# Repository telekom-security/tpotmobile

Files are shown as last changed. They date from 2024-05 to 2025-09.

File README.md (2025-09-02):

The idea for T-Pot Mobile started a couple of years back when T-Pot started to support the ARM64 architecture. Raspberry Pi hardware was hard to come by at reasonable prices so the journey took a little longer than anticipated. Started as a one-day-a-month project at work, it fastly turned into a weekend / evening project (winter was coming) and the first version was done in [December 2023](https://www.linkedin.com/posts/mochse_telekomsecurity-cyberdefense-raspberrypi-activity-7138560366661300224-Ccra).<br><br>
While already being an eye catcher the display was not bright enough, the resistive touchpanel and the resolution really did limit the possibilities. In consequence a new display had to be found that helped overcome the drawbacks. The Waveshare 4.3" capacitive display was a great choice with a higher resolution.<br><br>
**Bigger is better** - and in this case (pun intended) it is really true. T-Pot Mobile now supports an 8" display to make it an even bigger eye catcher!<br><br> To support the 8" display alongside the 4.3" a new case had to to be created while adjusting the code to make use of the added screen estate. <br><br>
We are very happy to share this project continiously as open source, with a huge thanks to [Telekom Security](https://geschaeftskunden.telekom.de/digitale-loesungen/cyber-security) to make this possible.<br><br>
**Create yours today, all files for 3d printing included!**

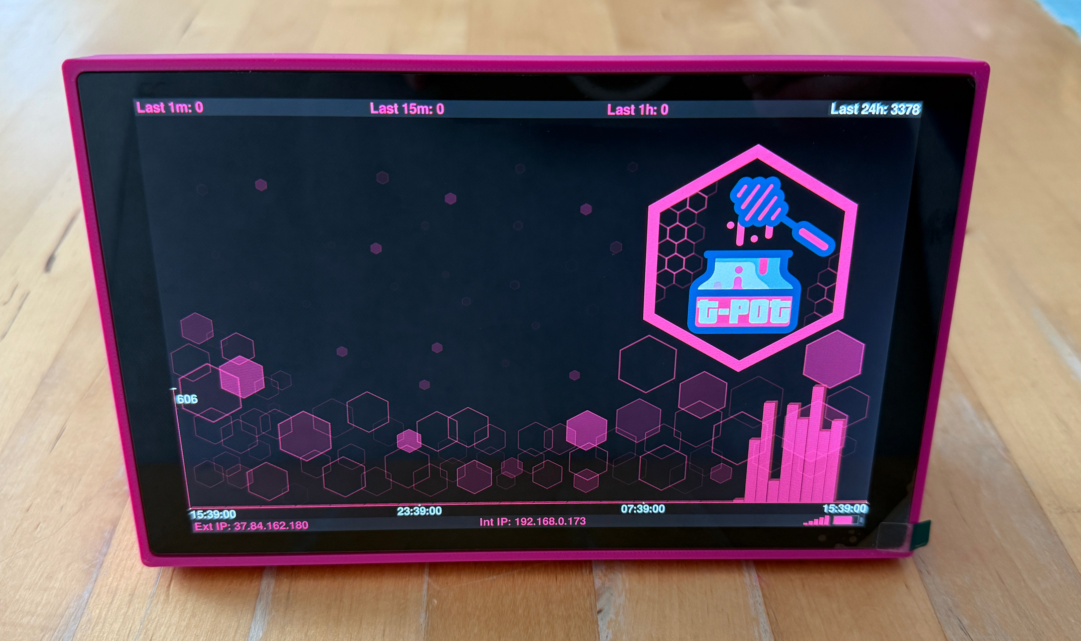
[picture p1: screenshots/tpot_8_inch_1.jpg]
T-Pot 8 inch 1


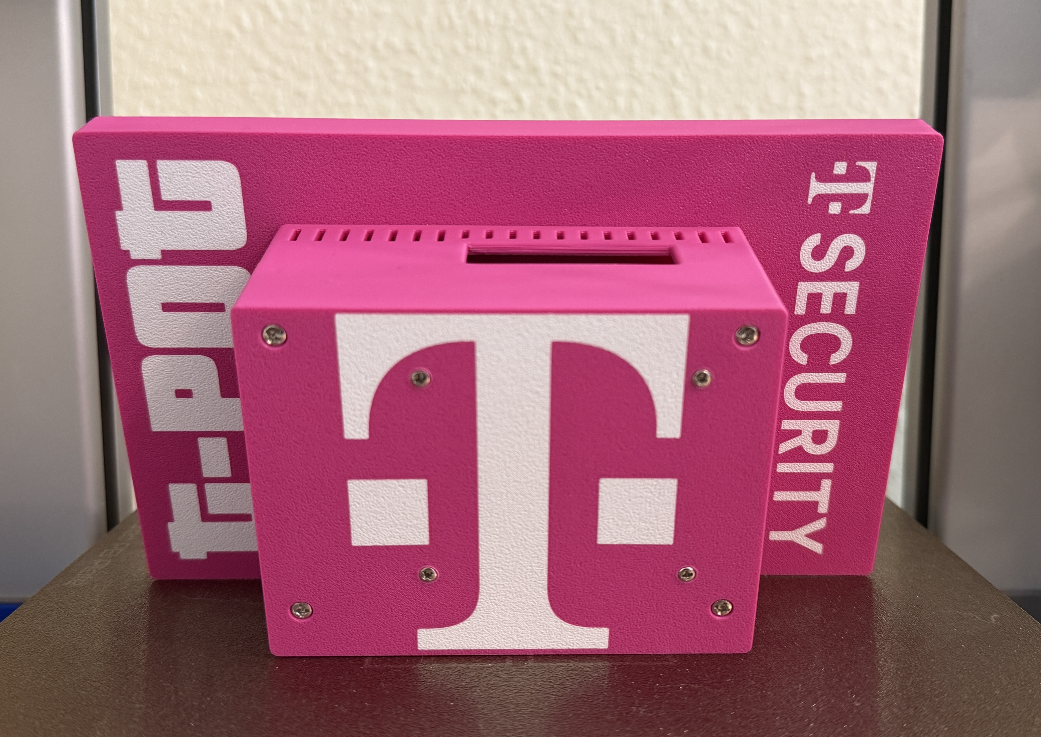
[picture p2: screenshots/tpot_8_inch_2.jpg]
T-Pot 8 inch 2


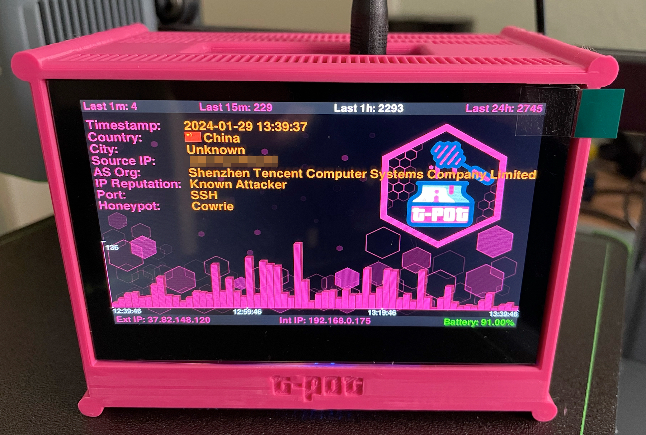
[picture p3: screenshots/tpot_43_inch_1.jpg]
T-Pot 4.3 inch 1


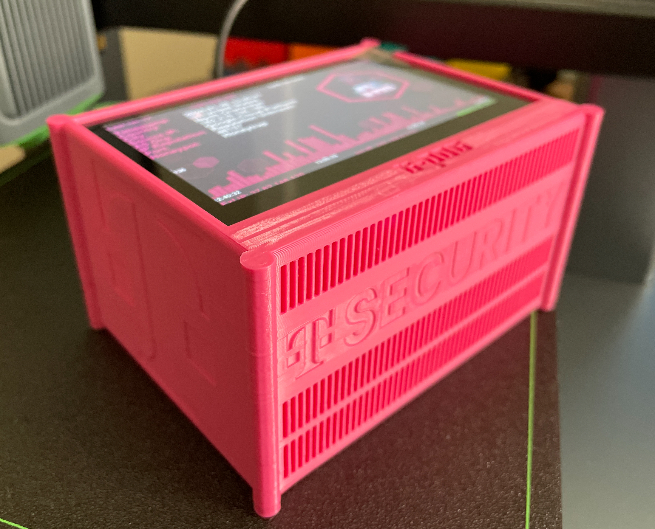
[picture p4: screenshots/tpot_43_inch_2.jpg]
T-Pot 4.3 inch 2


# T-Pot Mobile

<!-- vscode-markdown-toc -->
* 1. [Hardware requirements](#Hardwarerequirements)
	* 1.1. [8 inch](#inch)
	* 1.2. [4.3 inch](#inch-1)
* 2. [Requirements](#Requirements)
* 3. [Installation](#Installation)
	* 3.1. [One liner installation](#Onelinerinstallation)
	* 3.2. [Manual installation](#Manualinstallation)
* 4. [LTE Stick settings](#LTESticksettings)
* 5. [Usage](#Usage)
	* 5.1. [Turn on](#Turnon)
	* 5.2. [Turn off](#Turnoff)
* 6. [T-Pot Mobile UI](#T-PotMobileUI)
	* 6.1. [Waiting for Elasticsearch](#WaitingforElasticsearch)
	* 6.2. [Stats Mode](#StatsMode)
	* 6.3. [Map Mode](#MapMode)
	* 6.4. [Open Dialog Box](#OpenDialogBox)
		* 6.4.1. [Cancel](#Cancel)
		* 6.4.2. [Map / Stats](#MapStats)
		* 6.4.3. [Reboot](#Reboot)
		* 6.4.4. [Power Off](#PowerOff)
* 7. [Maintenance and Troubleshooting](#MaintenanceandTroubleshooting)
	* 7.1. [Connect a keyboard](#Connectakeyboard)
	* 7.2. [Exit the GUI](#ExittheGUI)
	* 7.3. [Starting / Stopping T-Pot services](#StartingStoppingT-Potservices)
	* 7.4. [Cronjob](#Cronjob)
	* 7.5. [Updates](#Updates)
	* 7.6. [Network Settings](#NetworkSettings)
* 8. [3d Print Settings](#dPrintSettings)
* 9. [Assembling the parts - 8 inch](#Assemblingtheparts-8inch)
* 10. [Assembling the parts - 4.3 inch](#Assemblingtheparts-4.3inch)
* 11. [Credits](#Credits)
* 12. [Licenses](#Licenses)

<!-- vscode-markdown-toc-config
	numbering=true
	autoSave=true
	/vscode-markdown-toc-config -->
<!-- /vscode-markdown-toc -->

##  1. Hardware requirements

T-Pot Mobile is developed specifically to make T-Pot a tangible, fully wireless honeypot using hardware components for:
<details>

<summary>

###  1.1. 8 inch

</summary>

- [Raspberry Pi 4 model B](https://www.raspberrypi.com/products/raspberry-pi-4-model-b/) with 8GB of RAM, 64GB microSD card
- [Waveshare 8" touch display](https://www.waveshare.com/8inch-dsi-lcd-c.htm)
- [Waveshare UPS HAT](https://www.waveshare.com/wiki/UPS_HAT) with 2 * 18650 batteries
- [ZTE MF79U Wingle CAT4-4G](https://www.amazon.de/gp/product/B08WPXRTRL) with the USB plug removed
- Nuts and standoff assortment for [M2.5](https://www.amazon.de/gp/product/B08M3BVC9Q) and [M3](https://www.amazon.de/gp/product/B08M3BVC9Q?th=1)

</details>

<details>

<summary>

###  1.2. 4.3 inch

</summary>

- [Raspberry Pi 4 model B](https://www.raspberrypi.com/products/raspberry-pi-4-model-b/) with 8GB of RAM, 64GB microSD card
- [Waveshare 4.3" touch display](https://www.waveshare.com/wiki/4.3inch_DSI_LCD), make sure to order the version including the [case](https://www.amazon.de/dp/B08LH5MFVS)
- [Waveshare UPS HAT](https://www.waveshare.com/wiki/UPS_HAT) with 2 * 18650 batteries
- [ZTE MF79U Wingle CAT4-4G](https://www.amazon.de/gp/product/B08WPXRTRL) with the USB plug removed
- [Nuts and standoff assortment](https://www.amazon.de/gp/product/B08M3BVC9Q) 

</details>

Regarding the hardware limits of the Raspberry Pi4 platform (mainly RAM and storage) T-Pot Mobile will use a `docker-compose.yml` specifically adjusted for this use case.

##  2. Requirements

- Raspbian Lite, 64bit based on Raspbian / Debian Bookworm
- At least T-Pot 24.04.0 which will be installed by the T-Pot Mobile installer
- Prepare the microSD Card with a user i.e. `tsec` and the WiFi settings for your local network (adjustments of the Wifi settings are described [here](#network-settings))

##  3. Installation

###  3.1. One liner installation
`env bash -c "$(curl -sL https://github.com/telekom-security/tpotmobile/raw/main/install.sh)"`

###  3.2. Manual installation
Boot the machine, SSH into Raspbian on `tcp/22`, run the following commands and follow the installer:
```
sudo apt install git
git clone https://github.com/telekom-security/tpotmobile
cd tpotmobile
bash install.sh
```

The `install.sh` script will also install T-Pot. When the installer asks for a T-Pot type, please choose `(M)obile` in order to download the correct docker images.

Then `sudo reboot` the machine, please notice after the reboot SSH will only be available via `tcp/64295`.

It takes about 8 minutes until all services are started successfully after installation.

##  4. LTE Stick settings
- Login: Factory default, adjust after setup
- SSID: Factory default, adjust after setup
- PSK: Factory default, adjust after setup
- For Telekom in Germany: Setup the LTE stick to use [APN with NAT Type 2](https://telekomhilft.telekom.de/t5/Mobilfunk/NAT-Typ-amp-APN-Einstellungen/td-p/3295081): `internet.t-d1.de`.
- Use NAT forwarding only for ports 1-64000 to avoid exposing T-Pot management ports, such as SSH.
- For DHCP / MAC settings ensure that the same IP will always be assigned to the T-Pot Wifi Adapter or NAT will break once a new IP lease starts.

##  5. Usage
###  5.1. Turn on
- After turning the device on (UPS HAT power switch in on-position) the device will automatically boot and wait for the mobile network / WiFi to be fully enabled.
- It takes roughly 8-10 minutes until all services have been started, then the first events should trickle in.
###  5.2. Turn off
- After [Shutting Down](#power-off) the device can be turned off (UPS HAT power switch in off-position). Always shutdown the device first to avoid damaging the elasticsearch index and / or filesystem.

##  6. T-Pot Mobile UI
The UI has been developed using Pygame (Raspbian / Debian Bookworm is fully supported and required).<br>
###  6.1. Waiting for Elasticsearch
- Once the device has started the UI will wait for Elasticsearch to be available, afterwards the UI will switch into stats mode (default: Last 1h). The UI can be fully utilized once events have been written to the Elasticsearch index.
###  6.2. Stats Mode
- A single touch will switch between the available timeframes (Last 1m, 15m, 1h, 24h).
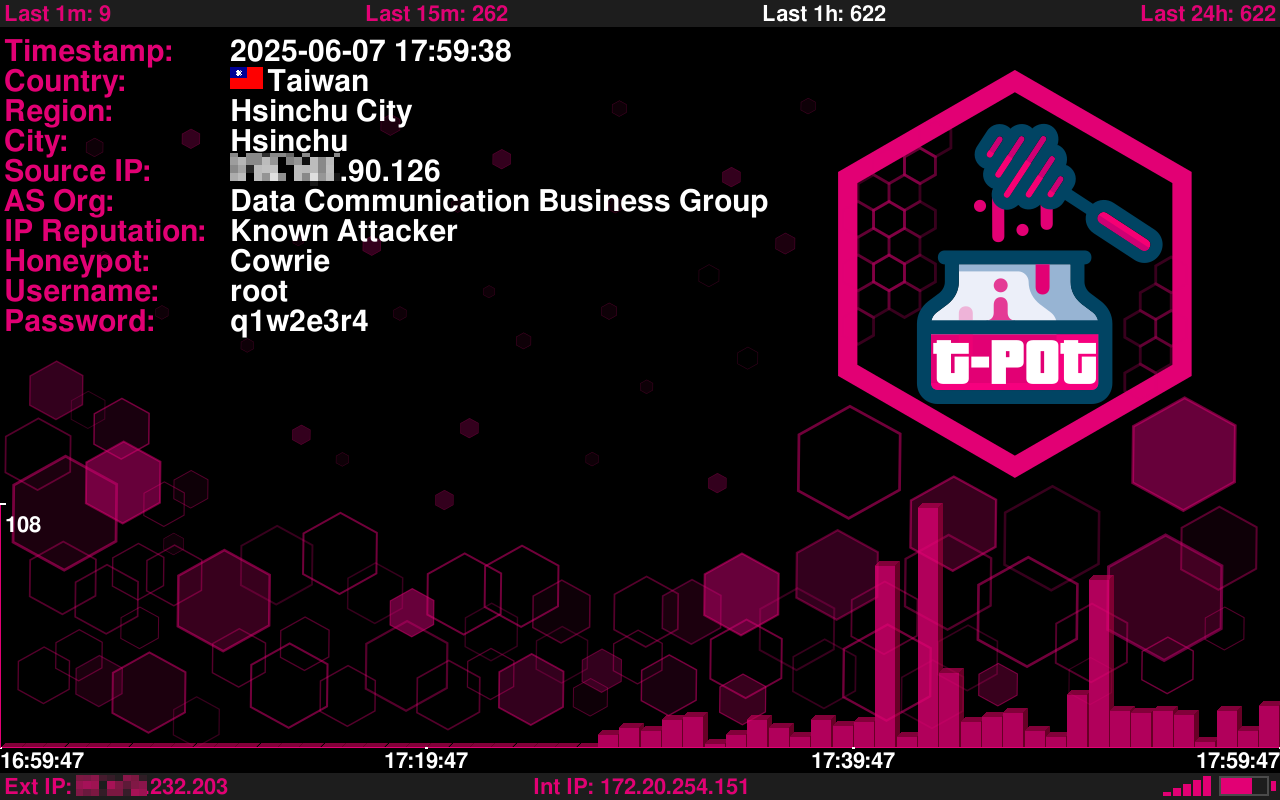
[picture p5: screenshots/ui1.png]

###  6.3. Map Mode
- In Map Mode the UI will display the events on a map utilizing some animations.
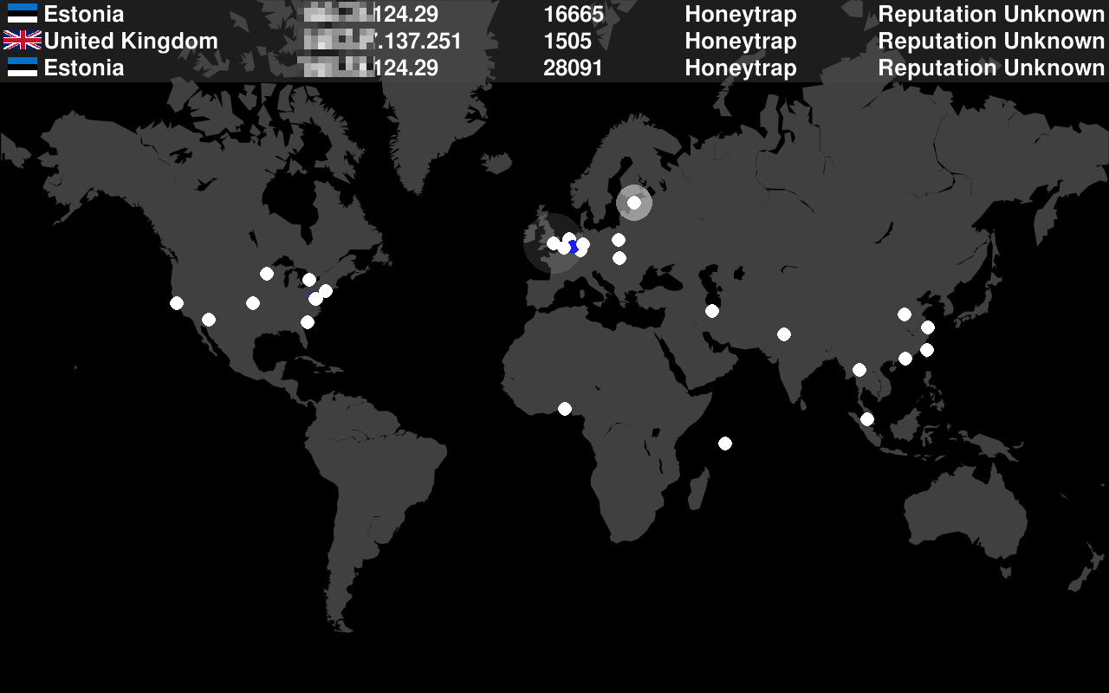
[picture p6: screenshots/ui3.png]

###  6.4. Open Dialog Box
- Swiping up from the bottom of the screen towards the top of the screen (at least half the height of the screen) will open the dialog box.
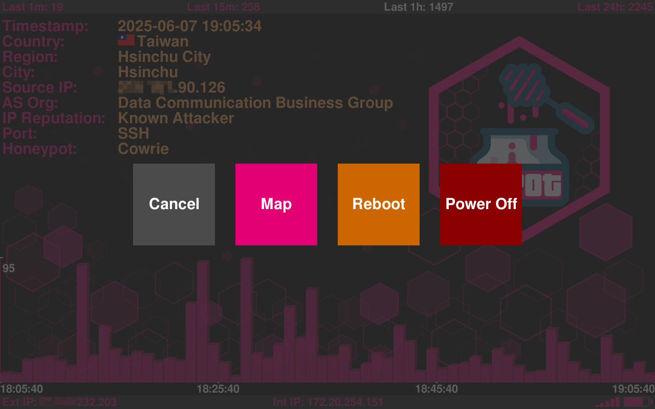
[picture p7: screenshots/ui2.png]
<br>
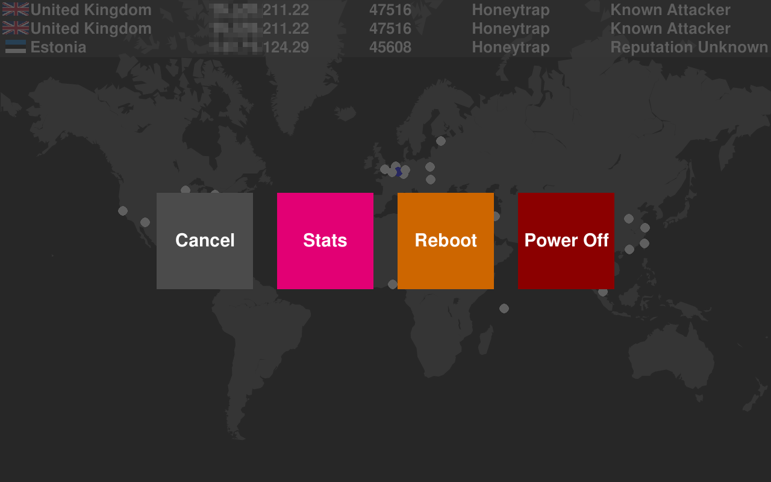
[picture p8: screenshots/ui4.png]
<br>
####  6.4.1. Cancel
- Will exit the dialog box. 
####  6.4.2. Map / Stats
- While in Stats mode the button will be called "Map" and when pressed will open the Map mode.
- While in Map mode the button will be called "Stats" and when pressed will open the Stats mode.
####  6.4.3. Reboot
- The Reboot button will reboot the system. 
####  6.4.4. Power Off
- The Power Off button will shut down the system. The system is designed for 24/7 operation, however it needs to be turned off using the Power Off function to avoid damaging the file system or elastic search indices.

##  7. Maintenance and Troubleshooting
###  7.1. Connect a keyboard
- For troubleshooting you can connect a keyboard.
###  7.2. Exit the GUI
- Press `q` to exit the GUI.
- Login to the system with your username, i.e. `tsec` and the password you chose.
- You now have access to the console as with any other Raspbian / Debian installation.
###  7.3. Starting / Stopping T-Pot services
- In `/etc/systemd/system` are the T-Pot systemd service files `tpot.service` and `tpotdisplay.service` located. While `tpot.service` does control the T-Pot services `tpotdisplay.service` controls the T-Pot Mobile GUI.
- Start T-Pot: `sudo systemctl start tpot.service`
- Start T-Pot Mobile GUI: `sudo systemctl start tpotdisplay.service`
- Stop T-Pot: `sudo systemctl stop tpot.service`
- Stop T-Pot Mobile GUI: `sudo systemctl stop tpotdisplay.service`
###  7.4. Cronjob
- T-Pot Mobile will restart the device by default every day. You can change the cronjob settings with `sudo crontab -e`.
###  7.5. Updates
- While OS updates will be installed automatically the docker image pull policy is set to `missing`. This means even if newer image versions are available `docker compose` will not pull them. If your mobile connection is perfectly fine with downloading large docker image files then you can adjust `TPOT_PULL_POLICY` in `tpotce/.env` to `always`. Otherwise install updates using a different network connection i.e. LAN / WiFi.
- Update tpotce: `cd tpotce && sudo systemctl stop tpot && git pull`
- Update tpotmobile: `cd tpotmobile && sudo systemctl stop tpotdisplay && git pull`
- Update docker images: `cd tpotce && docker compose -f docker-compose.yml pull`
###  7.6. Network Settings
- Raspbian uses Network Manager by default.
- You can find and adjust network connections in `/etc/NetworkManager/system-connections`.
- By default you will find `preconfigured.nmconnection` which contains the settings provided by Raspberry Pi Imager.

##  8. 3d Print Settings
For 3d printing we were using PLA+ filament with the following settings, depending on your usage other filament types need to be considered i.e. PETG, ABS or ASA (those remain untested regarding the case).
- #### Layers and perimeters
  - Layer height 0,2mm
  - 5 solid base and top layers with monotonic lines
  - 6 walls
- #### Infill
  - 25%
- #### Speed
  - Initial layer: 50mm/s
  - Outer wall: 60mm/s
- #### Supports enabled
    - Style: Grid
    - Top / bottom contact Z distance: 0.2 (reduce top to 0.1 may increase quality)
    - Base Pattern: Rectilinear grid
    - Pattern angle: 90°
    - Top / bottom interface layers: 2
    - Interface Pattern: Rectilinear

<details>

<summary>

##  9. Assembling the parts - 8 inch

</summary>

####
Overview of all the parts you will need to assemble T-Pot Mobile.
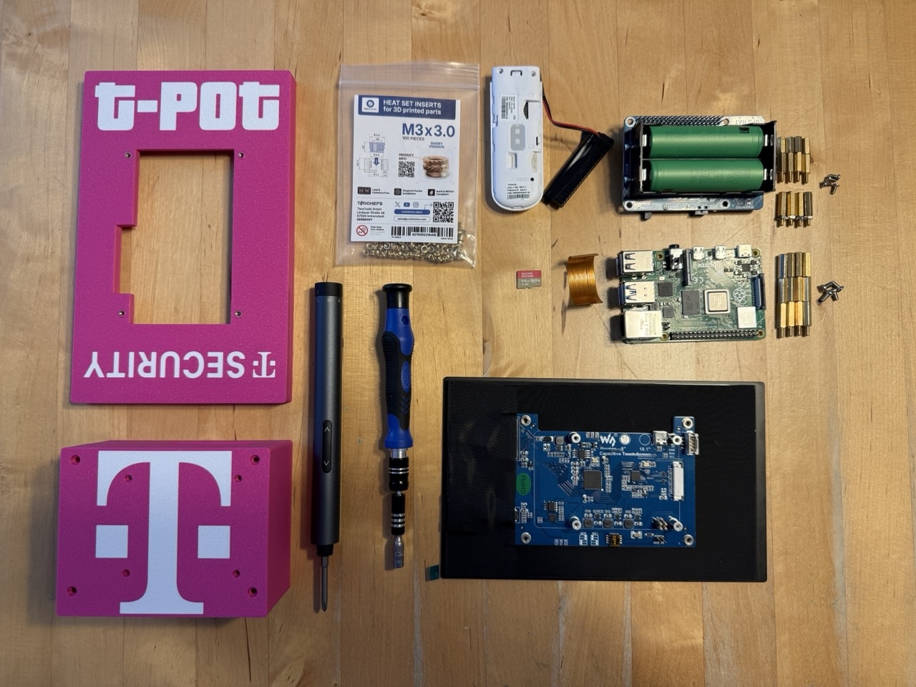
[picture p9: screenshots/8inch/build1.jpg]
Build 1


#### 
Insert the microSD card into the Pi4, **after** installing Raspbian. It will be harder to reach the microSD card later in the process.
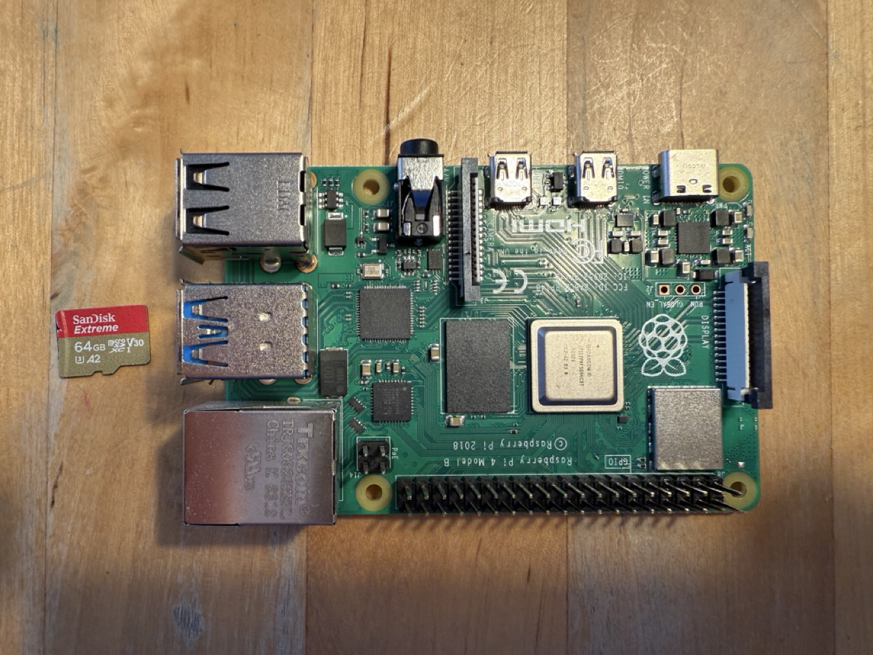
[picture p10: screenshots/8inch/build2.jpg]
Build 2

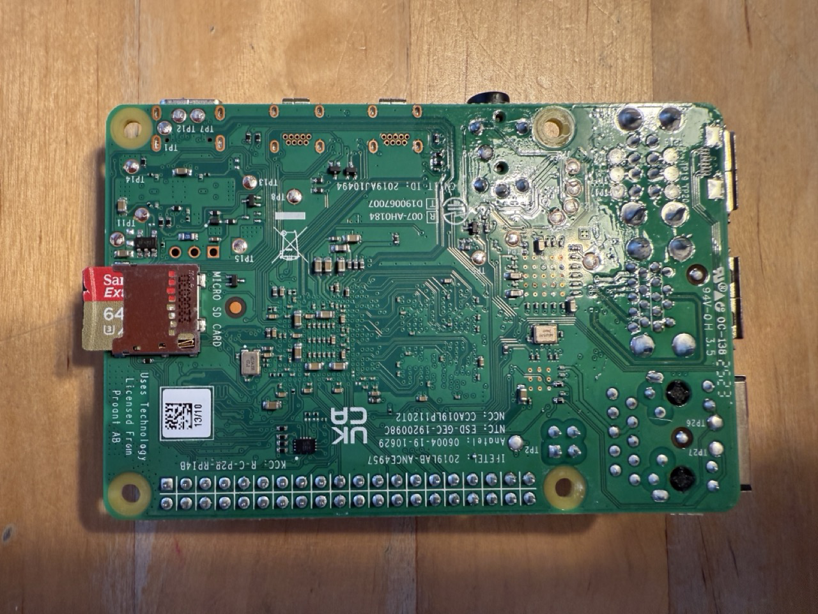
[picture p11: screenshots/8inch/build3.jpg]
Build 3


#### 
Place the screen in front of you, face down.
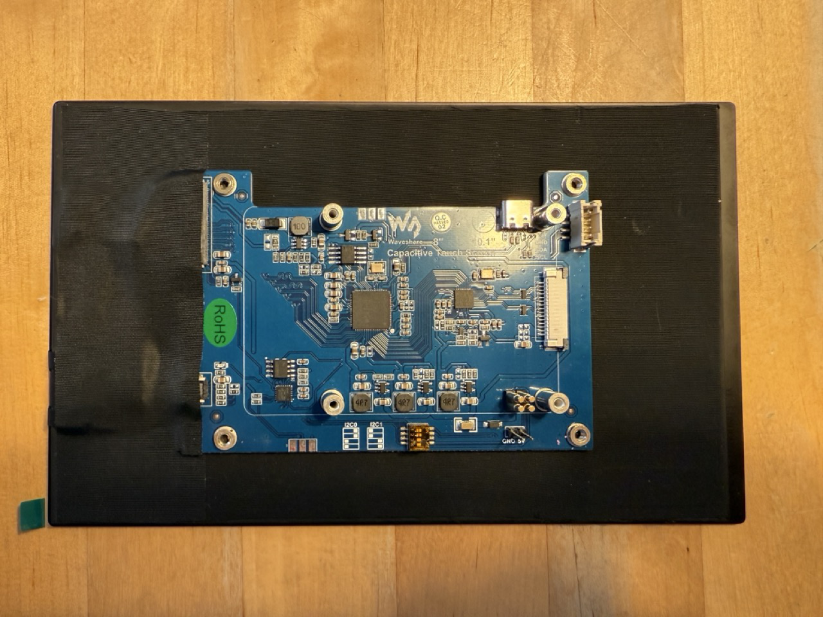
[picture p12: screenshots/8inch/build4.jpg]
Build 4


#### 
Align the Raspberry Pi on the standoffs and use the nuts (4 x M2.5) and standoffs (4 x M2.5x15 + 6) from the assortment to secure it. Also check the pogo pins align properly between the Pi and the display.
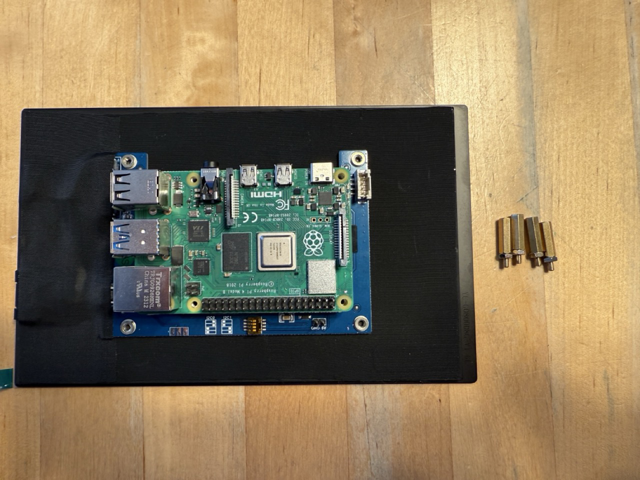
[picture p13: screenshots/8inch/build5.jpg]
Build 5

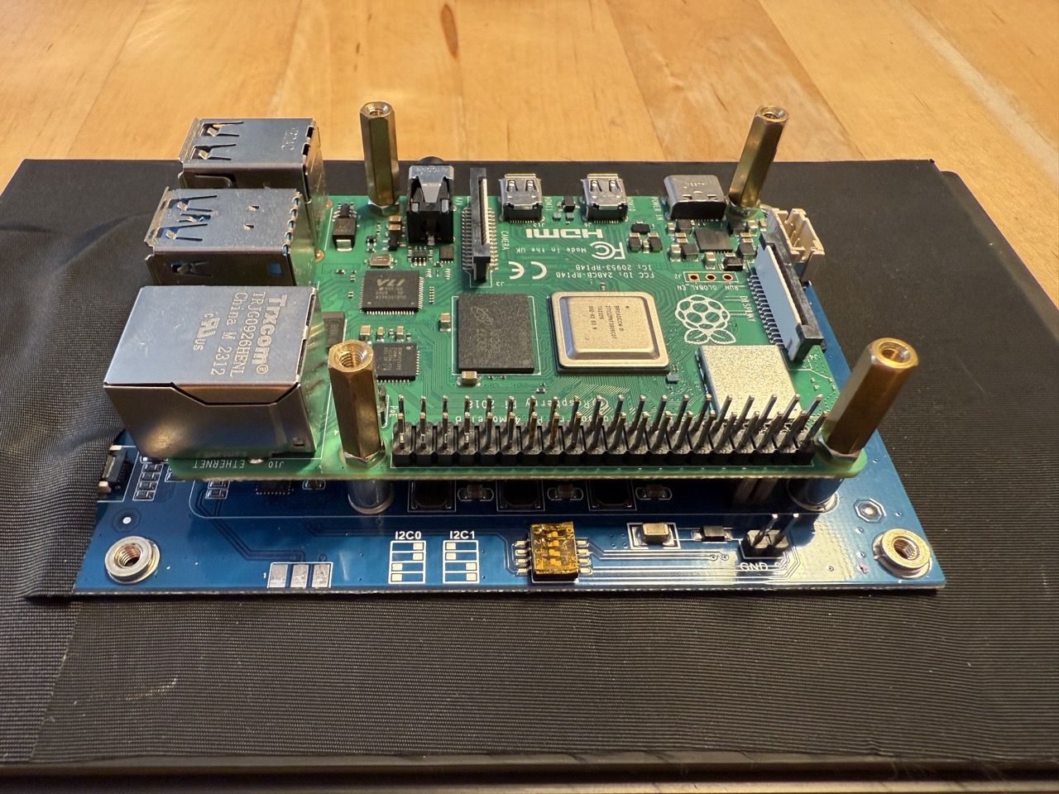
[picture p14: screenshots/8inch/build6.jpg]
Build 6


#### 
Insert the flex DSI cable and ensure the cable and socket connectors align and the pins face each other.
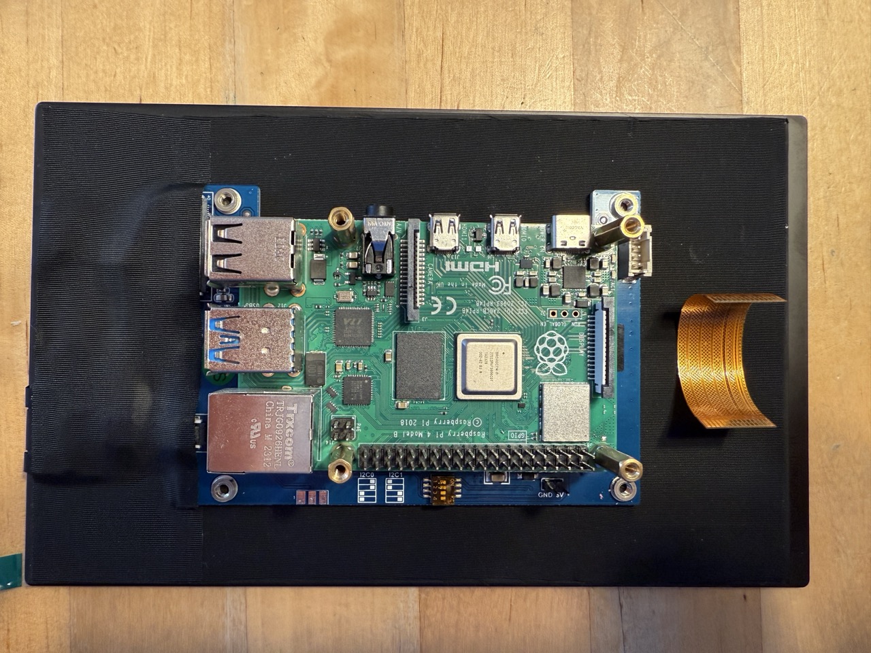
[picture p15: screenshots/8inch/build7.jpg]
Build 7

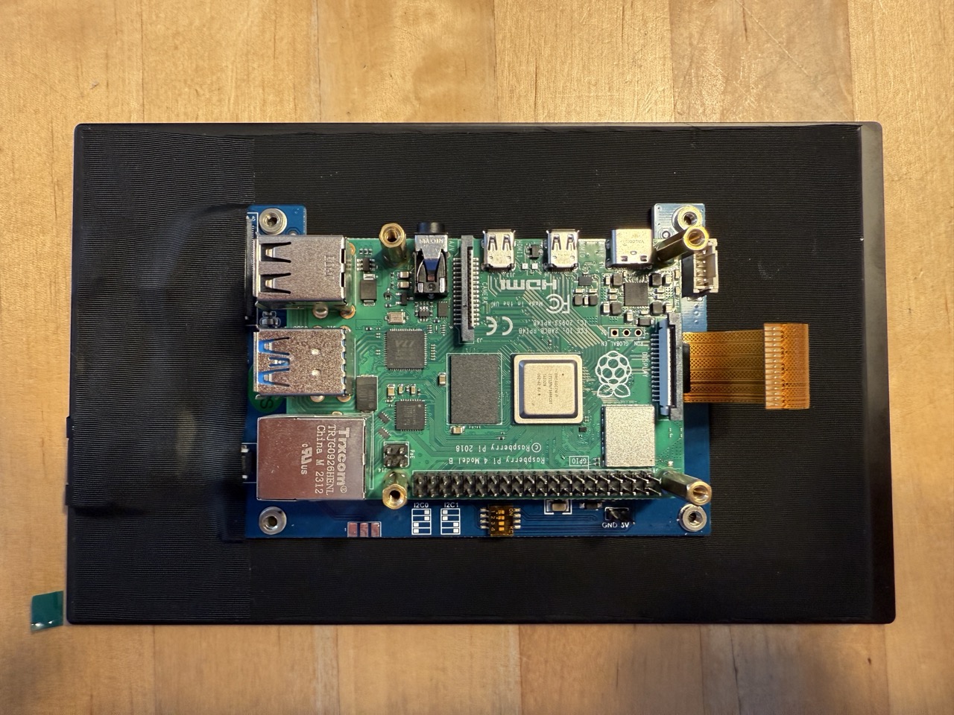
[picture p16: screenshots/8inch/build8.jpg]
Build 8

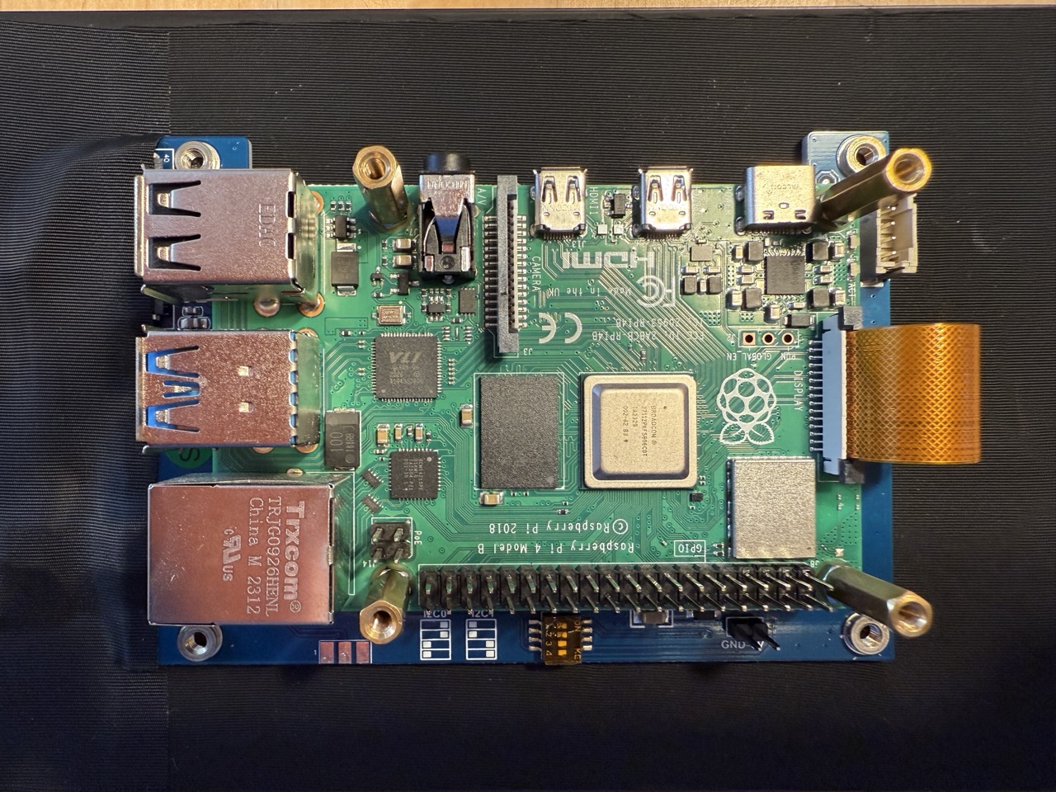
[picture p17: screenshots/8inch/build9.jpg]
Build 9

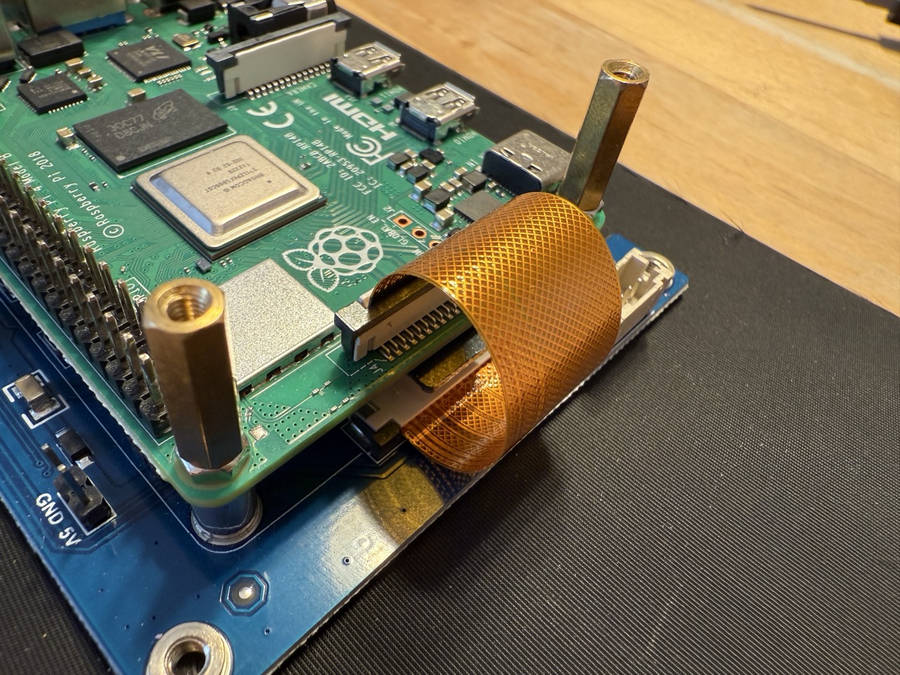
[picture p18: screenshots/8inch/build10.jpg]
Build 10


#### 
Install the UPS HAT on top of the Pi4.
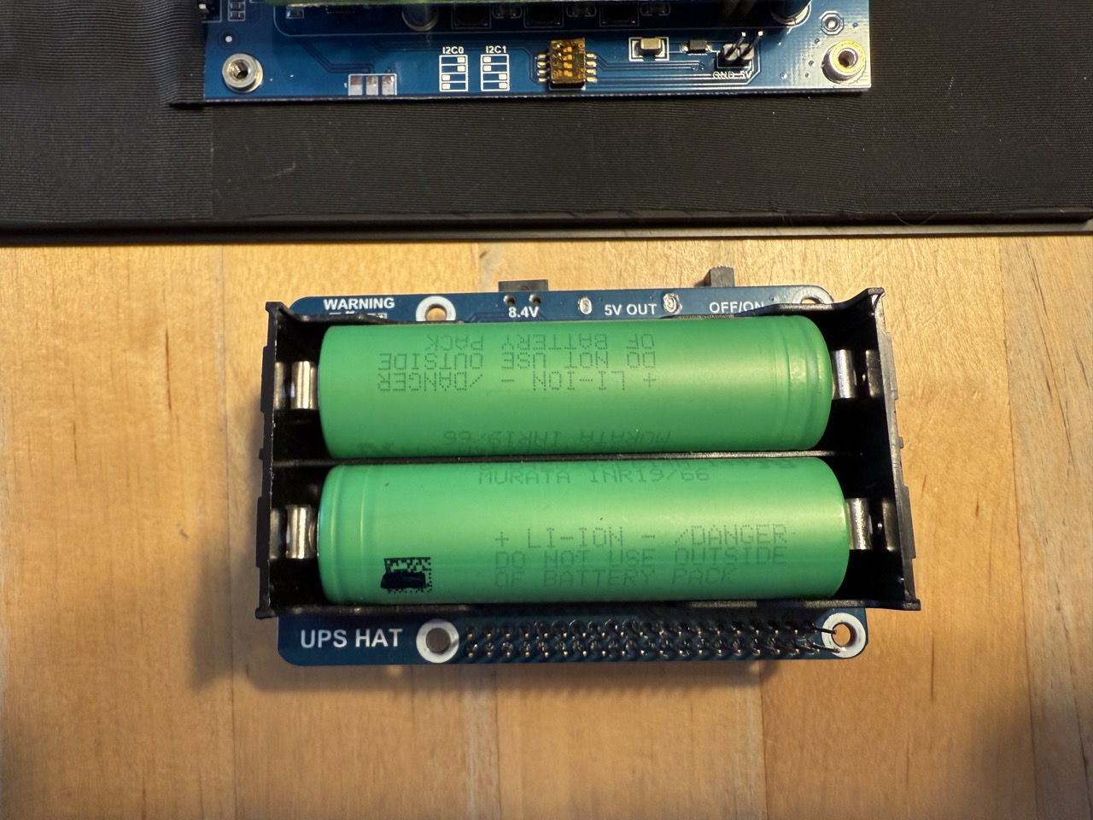
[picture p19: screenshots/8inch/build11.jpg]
Build 11

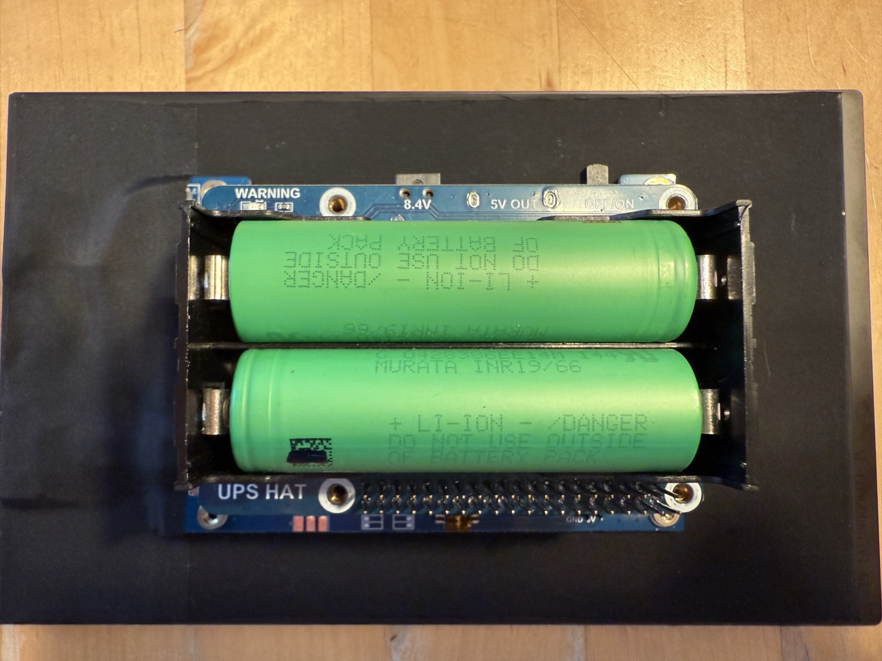
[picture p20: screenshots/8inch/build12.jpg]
Build 12

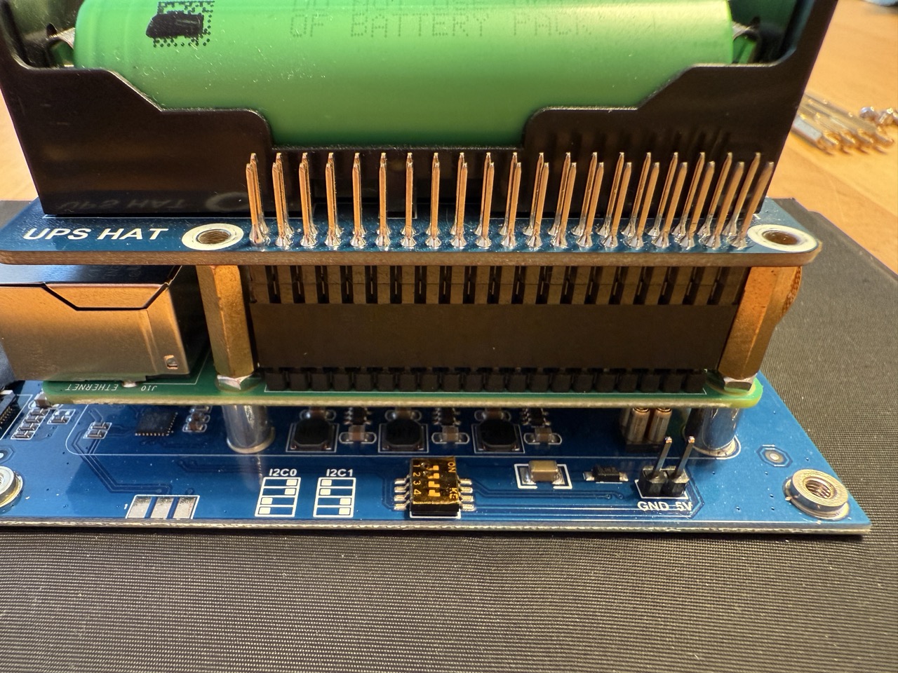
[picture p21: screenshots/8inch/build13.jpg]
Build 13


####
Now secure it with the standoffs (M2.5x12+6 + M2.5x10+6) as shown.
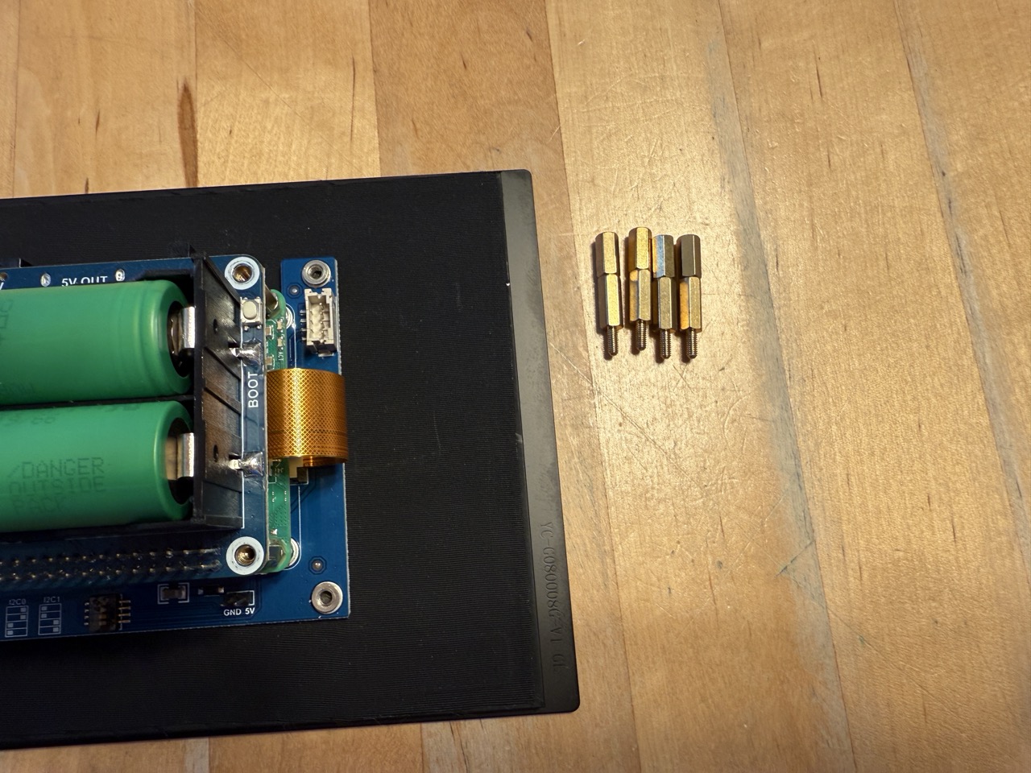
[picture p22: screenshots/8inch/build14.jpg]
Build 14

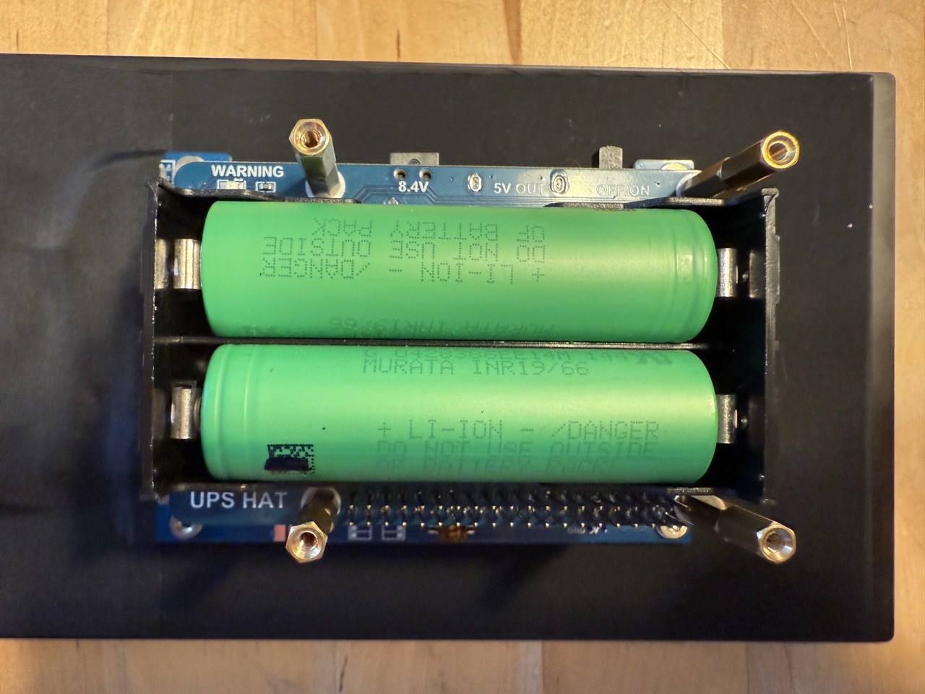
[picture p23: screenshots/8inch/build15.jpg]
Build 15

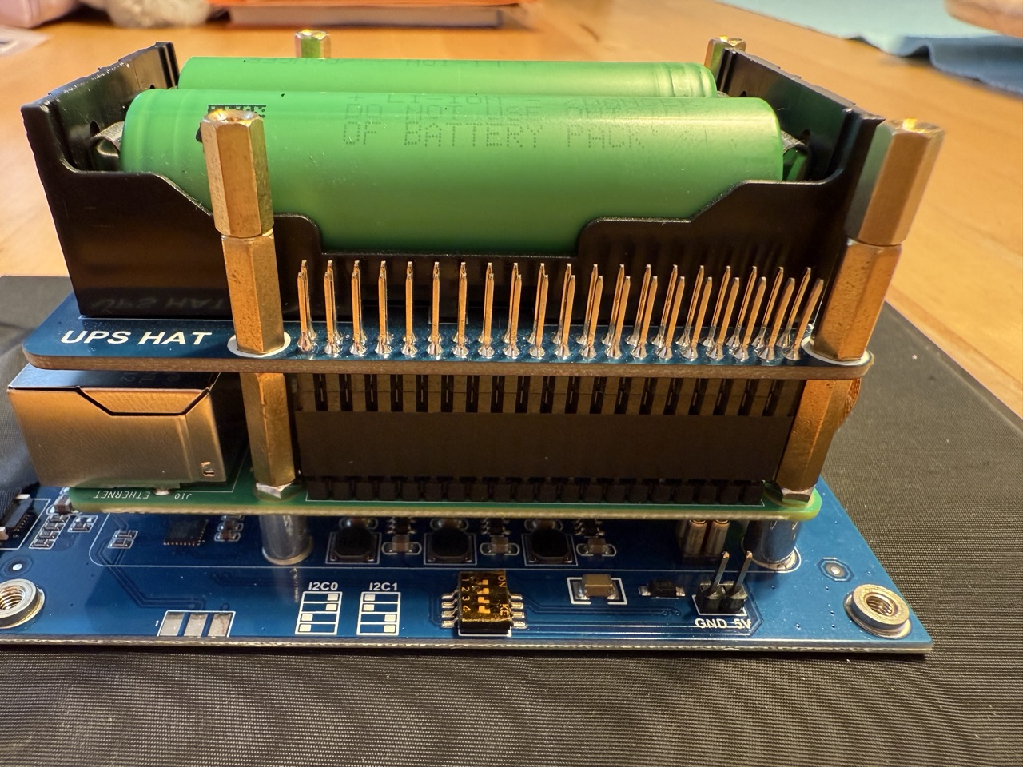
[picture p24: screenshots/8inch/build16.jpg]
Build 16


#### 
If you are using the LTE stick you have probably soldered the power connectors to a stacking HAT. You can now place it on top of the UPS HAT.
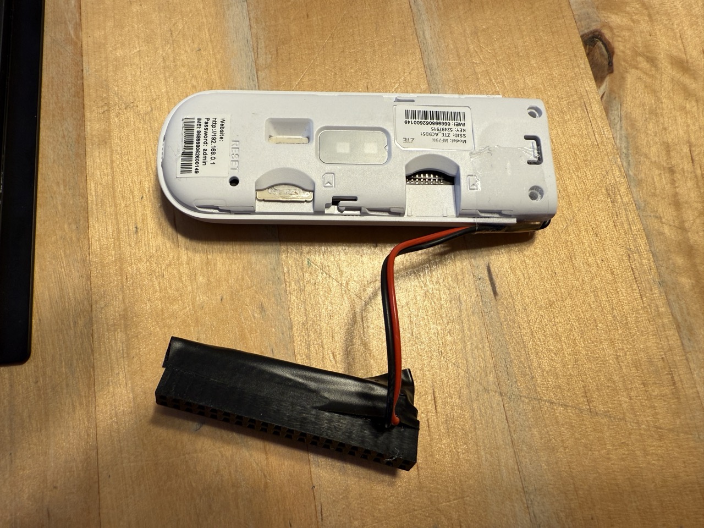
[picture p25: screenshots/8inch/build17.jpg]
Build 17

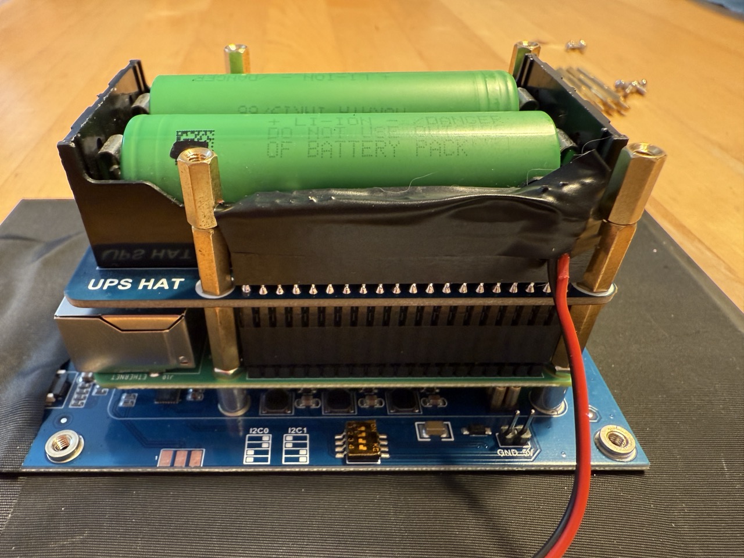
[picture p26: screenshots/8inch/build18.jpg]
Build 18


####
Now is a good time to test everything before putting it into the case. Connect the power supply to the UPS HAT and switch the UPS HAT on.

#### 
Now attach the top side of the case to the display to the 3d printed case.
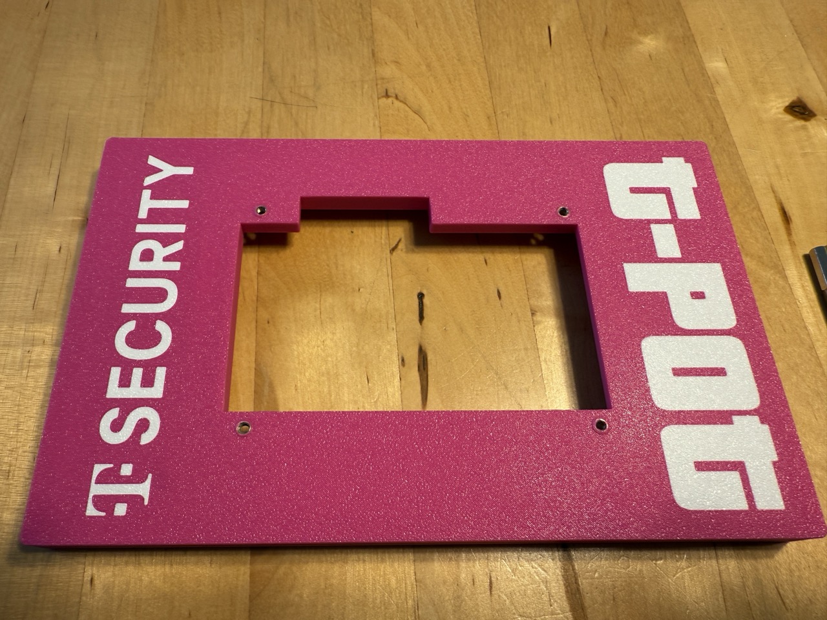
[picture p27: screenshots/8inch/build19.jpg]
Build 19

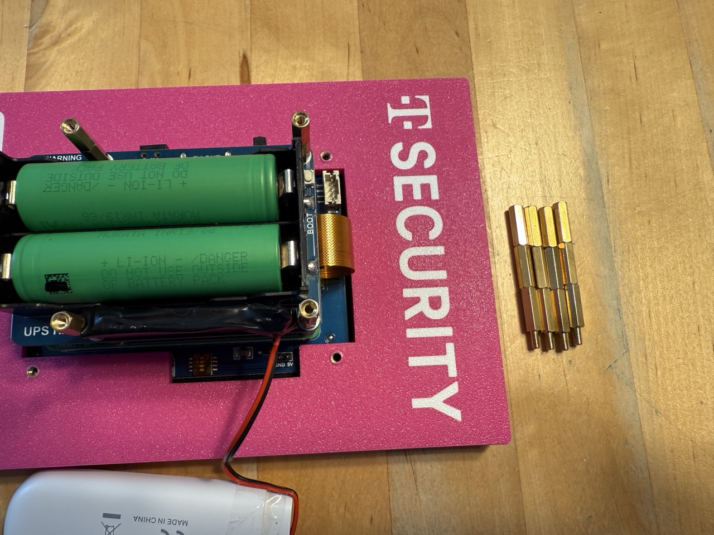
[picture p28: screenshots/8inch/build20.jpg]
Build 20

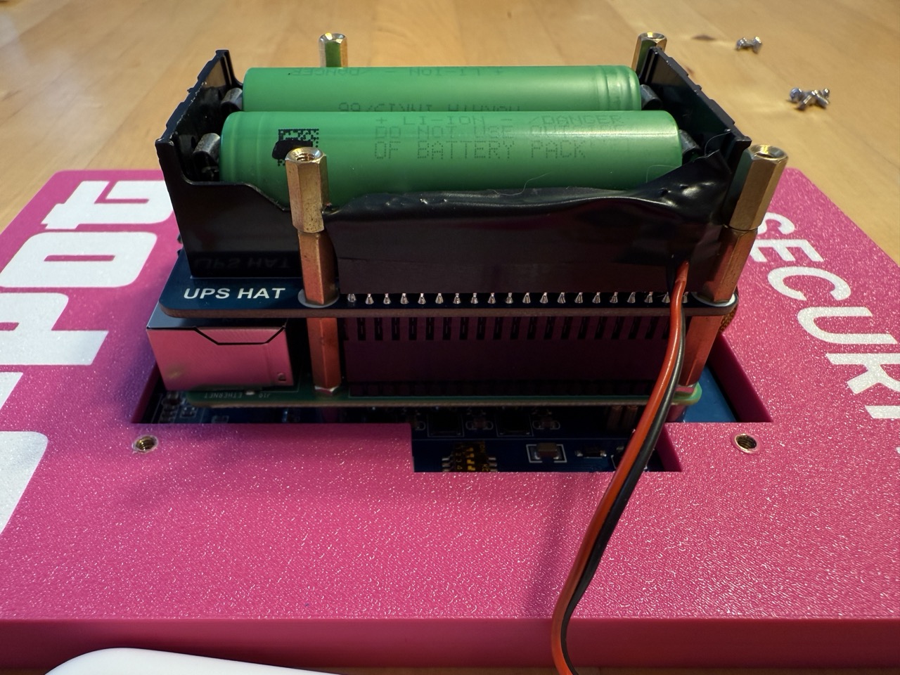
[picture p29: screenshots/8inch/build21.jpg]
Build 21


###
Now screw the M3x15 standoffs (as shown) into place. In both cases (heated inserts or not) make sure to not overtighten them, as the display standoffs have the tendency to snap off (do not ask how I know that). You can also use standoffs with a shorter end.

If you use heated inserts:
- Make sure the standoffs align properly in a 90° angle, otherwise the heated inserts need re-alignment.
- While screwing the standoffs into place slightly put pressure on the same position on the front of the display, so the standoffs get a grip on the display.

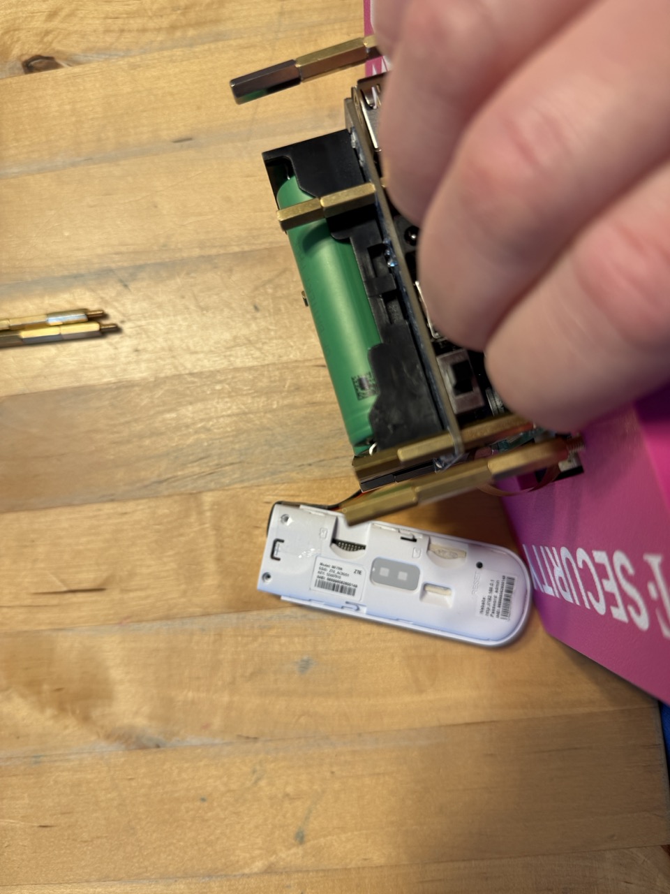
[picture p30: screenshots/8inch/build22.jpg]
Build 22


###
Now take the bottom of the 3d printed case and slide the LTE stick into its casket.
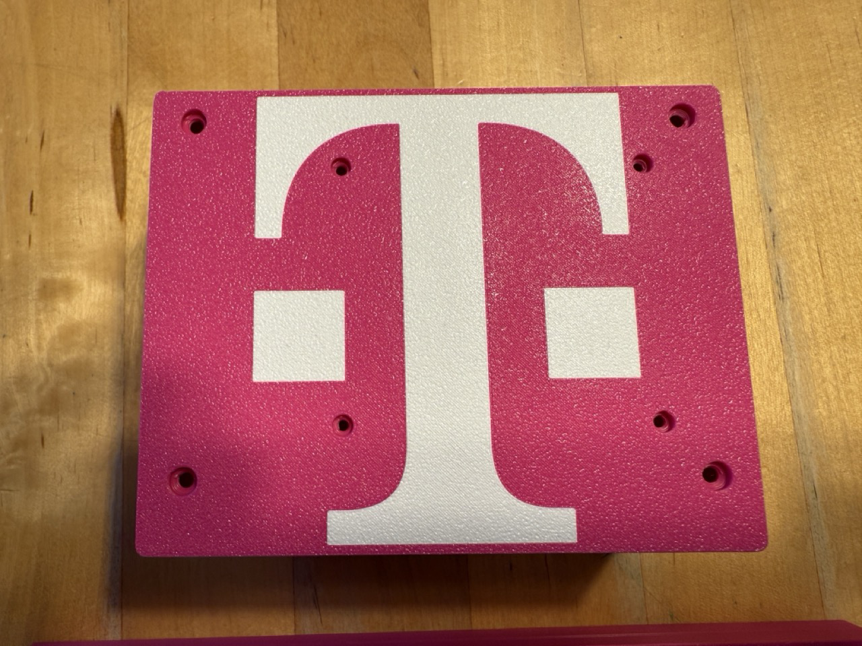
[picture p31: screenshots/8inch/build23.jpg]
Build 23

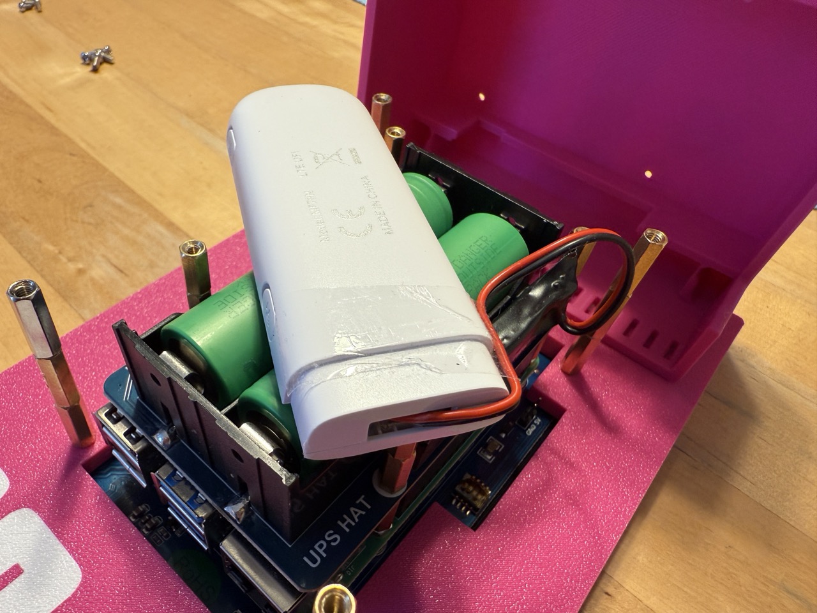
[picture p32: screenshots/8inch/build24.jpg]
Build 24

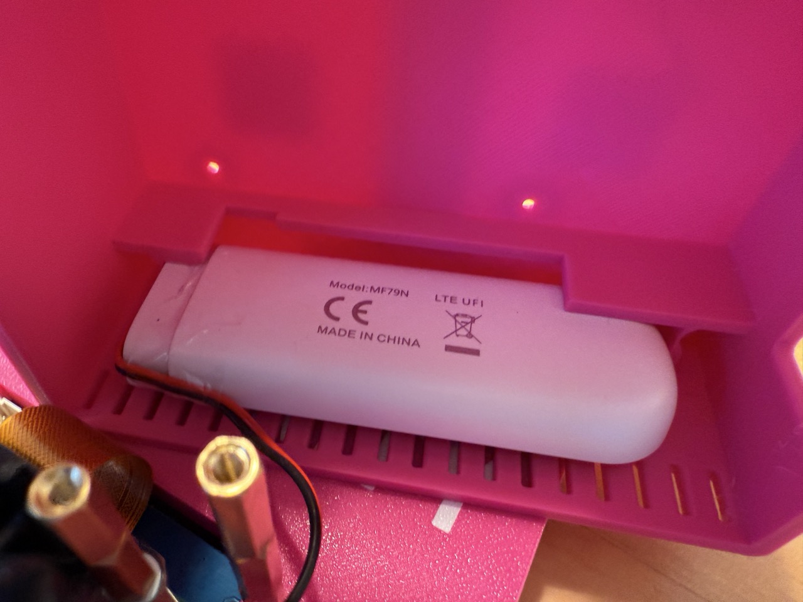
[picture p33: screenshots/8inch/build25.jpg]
Build 25

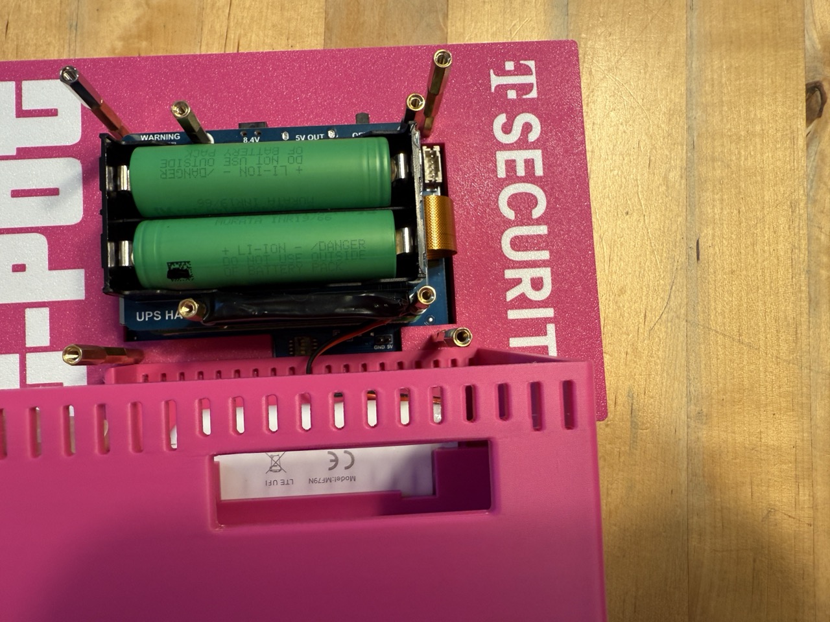
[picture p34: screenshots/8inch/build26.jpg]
Build 26


#### 
Hold the bottom of the case in place and screw the Phillips-head screws in. Start with the four M2.5 screws for the four inner holes and then use the four M3 for the outer holes.
Never overtighten the screws. Should they not line up properly gently take the bottom case off and do a fitting or adjustment of the holes.
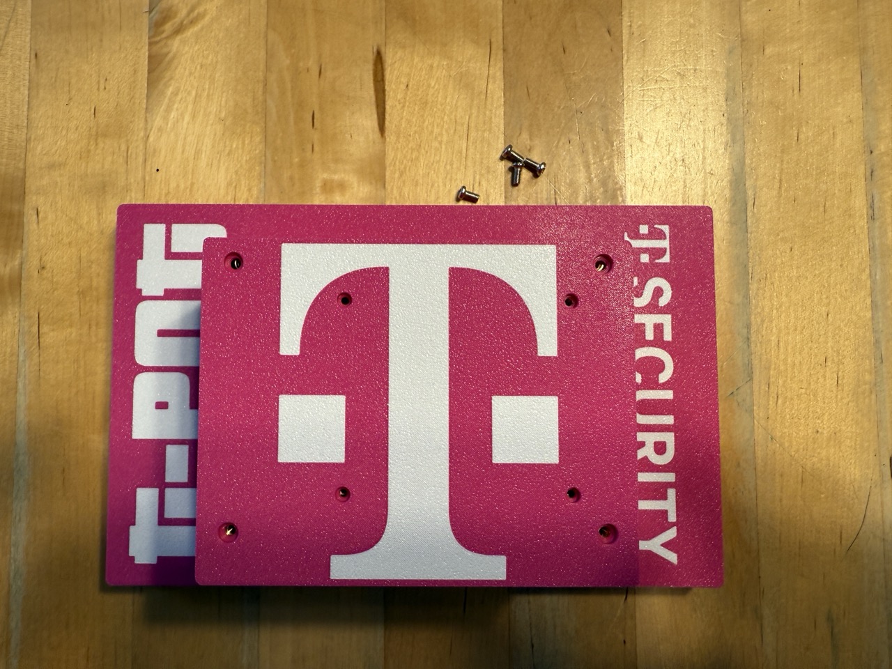
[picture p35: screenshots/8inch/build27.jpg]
Build 27

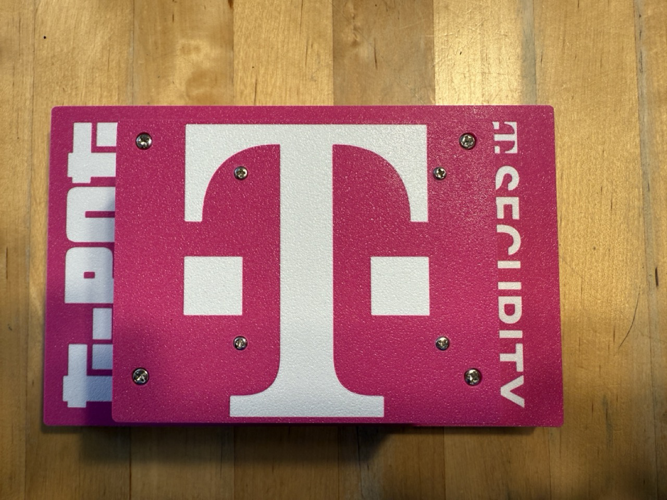
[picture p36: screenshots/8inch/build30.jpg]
Build 30


#### 
Done. Now connect the power supply (barrel connector) and turn the UPS HAT on. Depending on your usage the UPS HAT will not fully charge the batteries if the Pi4 is in use.
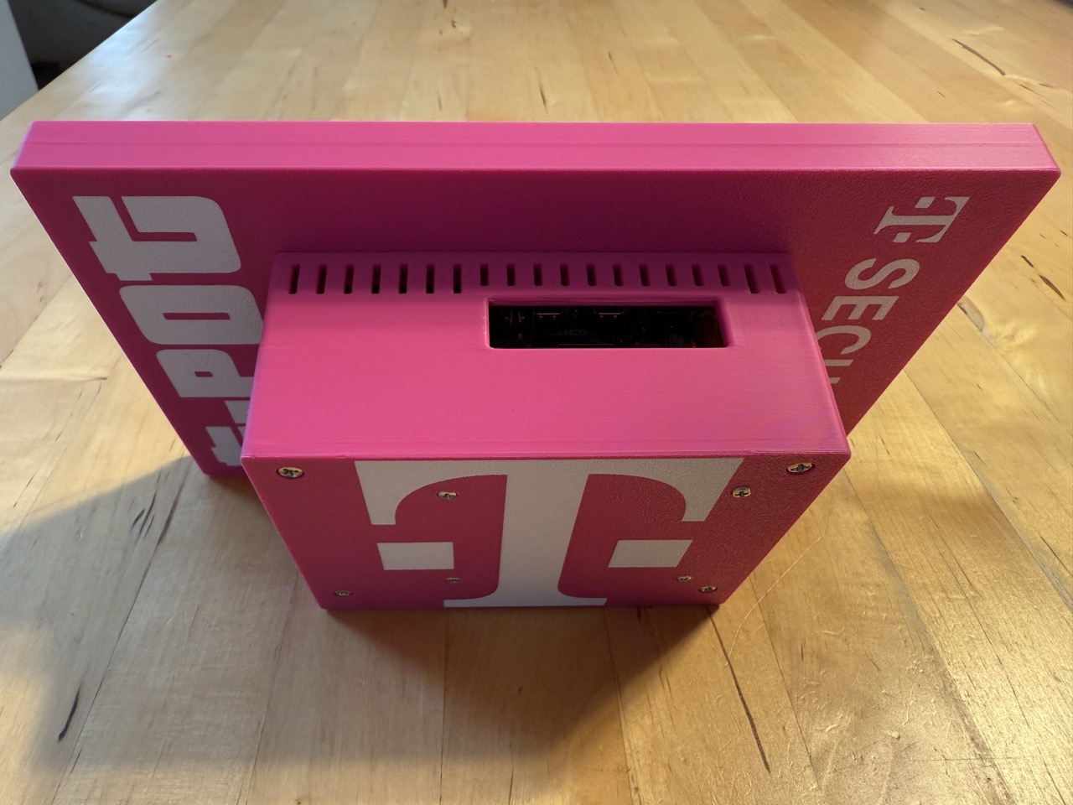
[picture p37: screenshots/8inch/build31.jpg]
Build 31

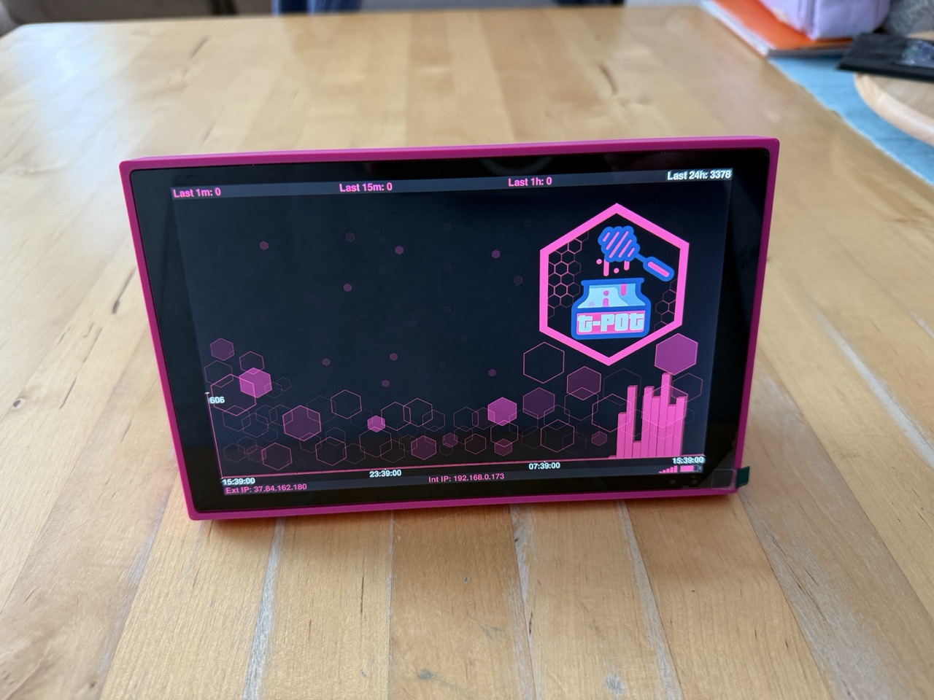
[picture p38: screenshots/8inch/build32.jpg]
Build 32


</details>

<details>

<summary>

##  10. Assembling the parts - 4.3 inch

</summary>

#### 
Make sure you ordered the display including the case, this will provide you with most of the required assembly parts, otherwise the case will not fit.

#### 
Place the display face down
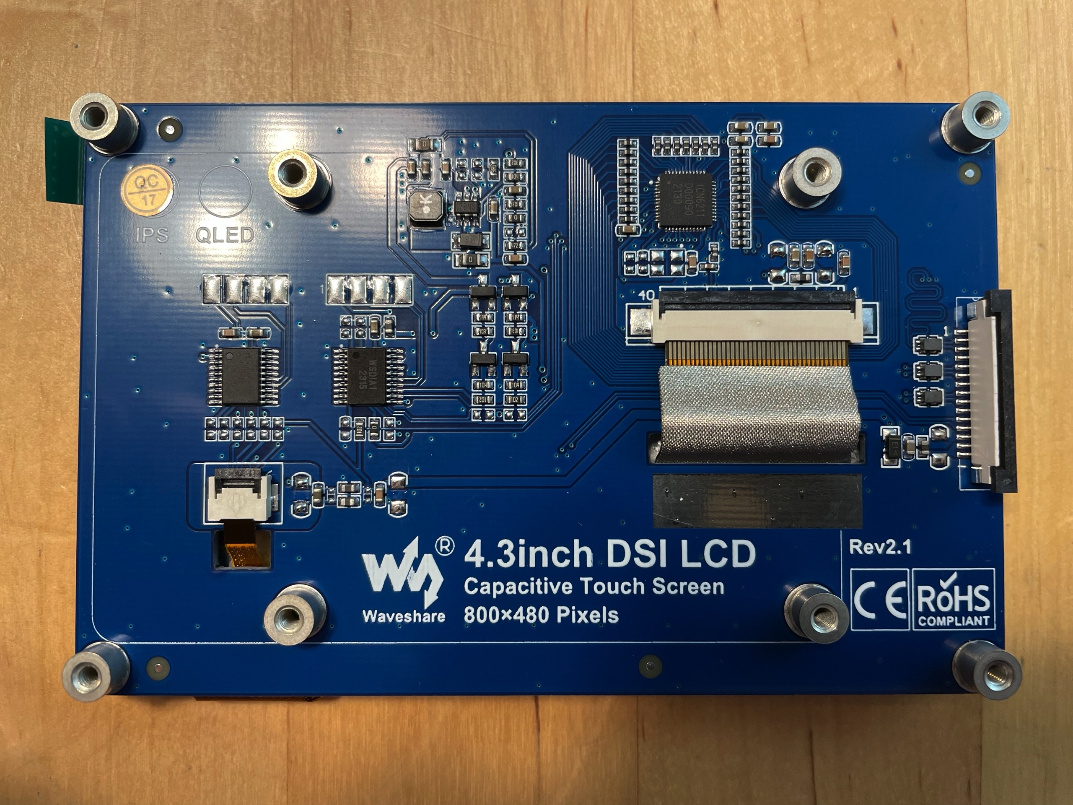
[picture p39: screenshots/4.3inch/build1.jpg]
Build 1


#### 
Insert the microSD card into the Pi4, **after** installing Raspbian. It will be harder to reach the microSD card later in the process.
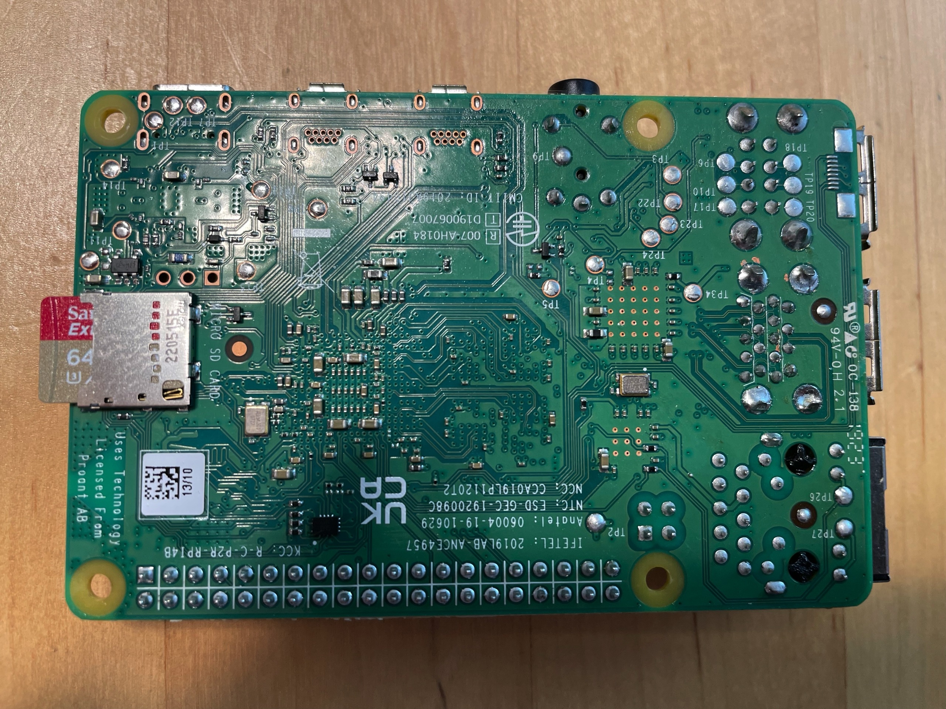
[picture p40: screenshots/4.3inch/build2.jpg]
Build 2


#### 
Screw the smallest standoffs in (included in the display / case package).
Build 3

#### 
Align the Raspberry Pi on the standoffs and use the nuts (4 x M2.5) and standoffs (4 x M2.5 + 6) from the assortment to secure it.
Build 4
Build 5

#### 
Insert the flex DSI cable and ensure the cable and socket connectors align and the pins face each other.
Build 6

####
Now screw the standoffs with the short end into the remaining four threads of the display backplate.
Build 7
Build 8

#### 
Install the UPS HAT on top of the Pi4 and secure it with the four phillips-head screws.
Build 9
Build 10

####
Add the remaining standoffs.
Build 11

####
Insert the batteries and be careful about polarity.
Build 12
Build 13
Build 14

#### 
If you are using the LTE stick you have probably soldered the power connectors to a stacking HAT. You can now place it on top of the UPS HAT.
Build 15

####
Now is a good time to test everything before putting it into the case. Connect the power supply to the UPS HAT and switch the UPS HAT on.
Build 16

#### 
Now put the LTE stick back into its case, insert the SIM card (which at this point should be setup not to require a PIN) and slide the LTE stick into its casket of the 3d printed case.

####
Slide the components carefully into the case and make sure not to damage the ribbon cable of the display.
Build 17
Build 18

#### 
Hold the display in place and turn the case upside down to secure the standoffs in the case using the Phillips-head screws.
Build 19

#### 
Done. Now connect the power supply (barrel connector) and turn the UPS HAT on. Depending on your usage the UPS HAT will only fully charge the batteries if the USB-C power supply for the Pi4 is connected as well.
Build 20

</details>

##  11. Credits
- Thanks to everyone who gave their feedback and thus leading the project to v3!
- Thanks to [Thomas Tschersich](https://www.linkedin.com/in/thomas-tschersich/) and [Thomas Breitbach](https://www.linkedin.com/in/dr-thomas-breitbach-34a519159/) who have T-Pot Mobile always readily available for our customers at [Telekom-Security](https://geschaeftskunden.telekom.de/digitale-loesungen/cyber-security).

##  12. Licenses
- Flags are provided by [Flagpedia](https://flagpedia.net).
- Display dtbo and ina219 module are provided by [Waveshare](https://www.waveshare.com), all copyrights apply.
- DTS overlays are provided by [RaspberryPi](https://github.com/raspberrypi/linux?tab=License-1-ov-file#readme).

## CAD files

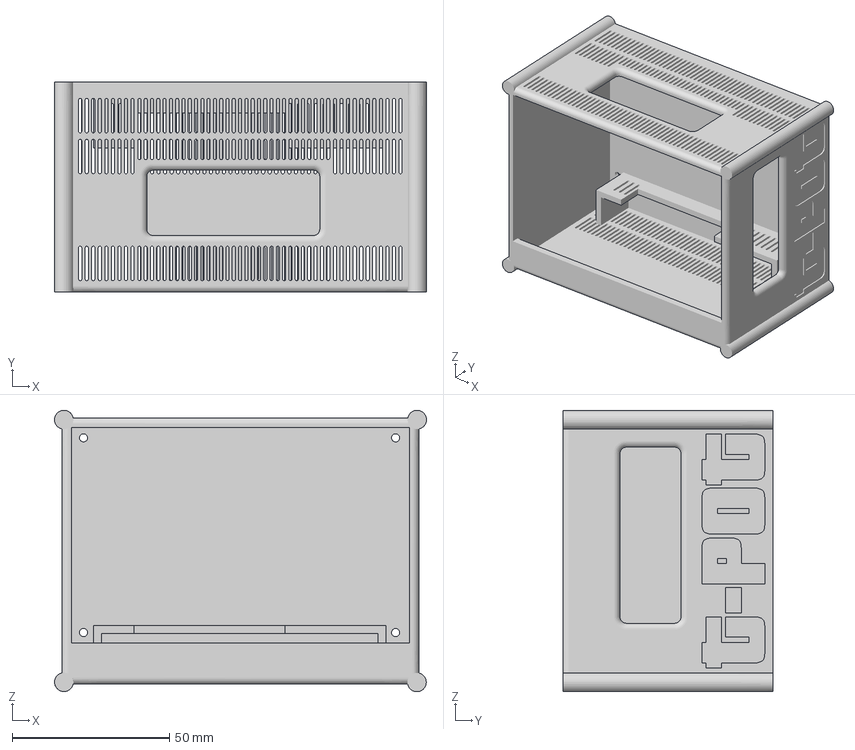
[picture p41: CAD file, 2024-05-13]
3d_stl/4_3_inch/tpot_case_v3.3mf
118.2 x 66.9 x 89.5 mm

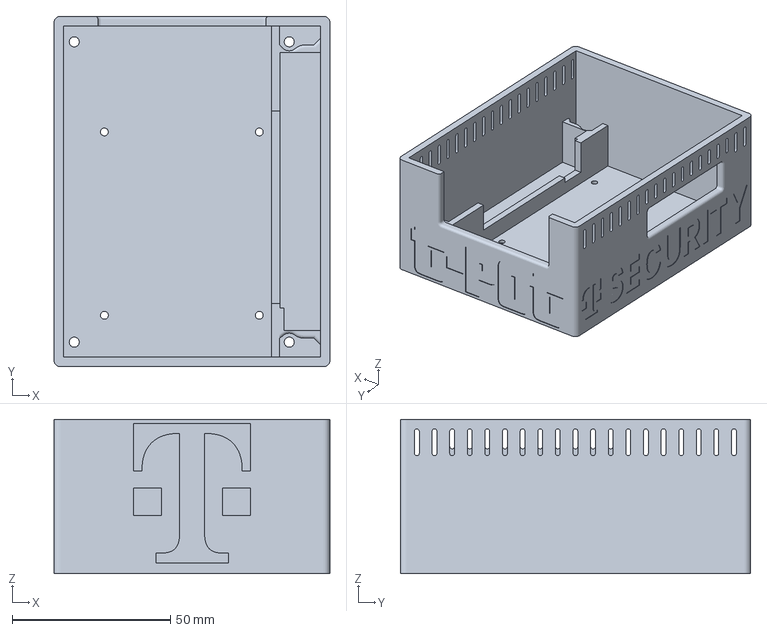
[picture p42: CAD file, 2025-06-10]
3d_stl/8_inch/T-Pot Case 8inch Bottom.3mf
87.3 x 110.9 x 48.8 mm

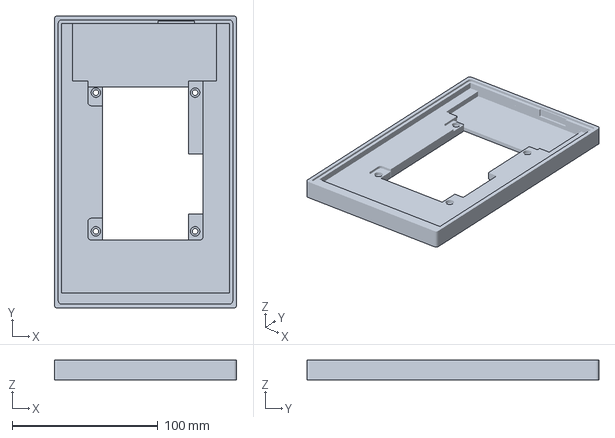
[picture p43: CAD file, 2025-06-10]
3d_stl/8_inch/T-Pot Case 8inch Top.3mf
125.0 x 200.0 x 13.6 mm

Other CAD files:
3d_stl/4_3_inch/tpot_case_v3.stl

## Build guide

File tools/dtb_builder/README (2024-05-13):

DTBOs for the SPI based Waveshare 3.5inch RPI LCD (C) do not work any longer with SDL / Pygame on Debian Bookworm.
The reason is the lacking Direct Rendering Manager support (DRM) which SDL relies on with KMSDRM to control the display.

General support is available with the Piscreen DTBO:
https://github.com/raspberrypi/linux/blob/rpi-6.1.y/arch/arm/boot/dts/overlays/piscreen-overlay.dts

However the DTBO's settings do not allow for screen rotation in KMS/DRM mode.

As a result a remix of these 3 DTBOs has been created with the GPIO includes being resolved to allow for easy compilation with dtc:
https://github.com/raspberrypi/linux/blob/rpi-6.1.y/arch/arm/boot/dts/overlays/piscreen-overlay.dts
https://github.com/raspberrypi/linux/blob/rpi-6.1.y/arch/arm/boot/dts/overlays/piscreen2r-overlay.dts
https://github.com/raspberrypi/linux/blob/rpi-6.1.y/arch/arm/boot/dts/overlays/watterott-display-overlay.dts

The resulting piscreen.dts is available in this folder and can be compiled with:
dtc -@ -I dts -O dtb -o piscreen.dtbo piscreen.dts

Then you need to copy it to the overlay folder:
sudo cp piscreen.dtbo /boot/overlays/

Run the piscreen_builder.sh script to compile the piscreen.dts and copy it to the tpotmobile/settings folder.
If you need adjustments after installation of the Raspberry Pi T-Pot copy the newly compiled piscreen.dtbo to the overlays folder.

The tpotmobile/settings folder will contain a config.txt example, however the installer will handle the adjustments.

Should the rotate / rotation settings not fit your setup you can adjust the piscreen.dts with 0, 90, 180 or 270. Then compile and reinstall it.

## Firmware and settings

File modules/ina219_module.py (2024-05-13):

import smbus2
import time

# Config Register (R/W)
_REG_CONFIG = 0x00
# SHUNT VOLTAGE REGISTER (R)
_REG_SHUNTVOLTAGE = 0x01

# BUS VOLTAGE REGISTER (R)
_REG_BUSVOLTAGE = 0x02

# POWER REGISTER (R)
_REG_POWER = 0x03

# CURRENT REGISTER (R)
_REG_CURRENT = 0x04

# CALIBRATION REGISTER (R/W)
_REG_CALIBRATION = 0x05


class BusVoltageRange:
    """Constants for ``bus_voltage_range``"""
    RANGE_16V = 0x00  # set bus voltage range to 16V
    RANGE_32V = 0x01  # set bus voltage range to 32V (default)


class Gain:
    """Constants for ``gain``"""
    DIV_1_40MV = 0x00  # shunt prog. gain set to  1, 40 mV range
    DIV_2_80MV = 0x01  # shunt prog. gain set to /2, 80 mV range
    DIV_4_160MV = 0x02  # shunt prog. gain set to /4, 160 mV range
    DIV_8_320MV = 0x03  # shunt prog. gain set to /8, 320 mV range


class ADCResolution:
    """Constants for ``bus_adc_resolution`` or ``shunt_adc_resolution``"""
    ADCRES_9BIT_1S = 0x00  # 9bit,   1 sample,     84us
    ADCRES_10BIT_1S = 0x01  # 10bit,   1 sample,    148us
    ADCRES_11BIT_1S = 0x02  # 11 bit,  1 sample,    276us
    ADCRES_12BIT_1S = 0x03  # 12 bit,  1 sample,    532us
    ADCRES_12BIT_2S = 0x09  # 12 bit,  2 samples,  1.06ms
    ADCRES_12BIT_4S = 0x0A  # 12 bit,  4 samples,  2.13ms
    ADCRES_12BIT_8S = 0x0B  # 12bit,   8 samples,  4.26ms
    ADCRES_12BIT_16S = 0x0C  # 12bit,  16 samples,  8.51ms
    ADCRES_12BIT_32S = 0x0D  # 12bit,  32 samples, 17.02ms
    ADCRES_12BIT_64S = 0x0E  # 12bit,  64 samples, 34.05ms
    ADCRES_12BIT_128S = 0x0F  # 12bit, 128 samples, 68.10ms


class Mode:
    """Constants for ``mode``"""
    POWERDOW = 0x00  # power down
    SVOLT_TRIGGERED = 0x01  # shunt voltage triggered
    BVOLT_TRIGGERED = 0x02  # bus voltage triggered
    SANDBVOLT_TRIGGERED = 0x03  # shunt and bus voltage triggered
    ADCOFF = 0x04  # ADC off
    SVOLT_CONTINUOUS = 0x05  # shunt voltage continuous
    BVOLT_CONTINUOUS = 0x06  # bus voltage continuous
    SANDBVOLT_CONTINUOUS = 0x07  # shunt and bus voltage continuous


class INA219:
    def __init__(self, i2c_bus=1, addr=0x40):
        self.bus = smbus2.SMBus(i2c_bus);
        self.addr = addr

        # Set chip to known config values to start
        self._cal_value = 0
        self._current_lsb = 0
        self._power_lsb = 0
        self.set_calibration_32V_2A()

    def read(self, address):
        data = self.bus.read_i2c_block_data(self.addr, address, 2)
        return ((data[0] * 256) + data[1])

    def write(self, address, data):
        temp = [0, 0]
        temp[1] = data & 0xFF
        temp[0] = (data & 0xFF00) >> 8
        self.bus.write_i2c_block_data(self.addr, address, temp)

    def set_calibration_32V_2A(self):
        """Configures to INA219 to be able to measure up to 32V and 2A of current. Counter
           overflow occurs at 3.2A.
           ..note :: These calculations assume a 0.1 shunt ohm resistor is present
        """
        # By default we use a pretty huge range for the input voltage,
        # which probably isn't the most appropriate choice for system
        # that don't use a lot of power.  But all of the calculations
        # are shown below if you want to change the settings.  You will
        # also need to change any relevant register settings, such as
        # setting the VBUS_MAX to 16V instead of 32V, etc.

        # VBUS_MAX = 32V             (Assumes 32V, can also be set to 16V)
        # VSHUNT_MAX = 0.32          (Assumes Gain 8, 320mV, can also be 0.16, 0.08, 0.04)
        # RSHUNT = 0.1               (Resistor value in ohms)

        # 1. Determine max possible current
        # MaxPossible_I = VSHUNT_MAX / RSHUNT
        # MaxPossible_I = 3.2A

        # 2. Determine max expected current
        # MaxExpected_I = 2.0A

        # 3. Calculate possible range of LSBs (Min = 15-bit, Max = 12-bit)
        # MinimumLSB = MaxExpected_I/32767
        # MinimumLSB = 0.000061              (61uA per bit)
        # MaximumLSB = MaxExpected_I/4096
        # MaximumLSB = 0,000488              (488uA per bit)

        # 4. Choose an LSB between the min and max values
        #    (Preferrably a roundish number close to MinLSB)
        # CurrentLSB = 0.0001 (100uA per bit)
        self._current_lsb = .1  # Current LSB = 100uA per bit

        # 5. Compute the calibration register
        # Cal = trunc (0.04096 / (Current_LSB * RSHUNT))
        # Cal = 4096 (0x1000)

        self._cal_value = 4096

        # 6. Calculate the power LSB
        # PowerLSB = 20 * CurrentLSB
        # PowerLSB = 0.002 (2mW per bit)
        self._power_lsb = .002  # Power LSB = 2mW per bit

        # 7. Compute the maximum current and shunt voltage values before overflow
        #
        # Max_Current = Current_LSB * 32767
        # Max_Current = 3.2767A before overflow
        #
        # If Max_Current > Max_Possible_I then
        #    Max_Current_Before_Overflow = MaxPossible_I
        # Else
        #    Max_Current_Before_Overflow = Max_Current
        # End If
        #
        # Max_ShuntVoltage = Max_Current_Before_Overflow * RSHUNT
        # Max_ShuntVoltage = 0.32V
        #
        # If Max_ShuntVoltage >= VSHUNT_MAX
        #    Max_ShuntVoltage_Before_Overflow = VSHUNT_MAX
        # Else
        #    Max_ShuntVoltage_Before_Overflow = Max_ShuntVoltage
        # End If

        # 8. Compute the Maximum Power
        # MaximumPower = Max_Current_Before_Overflow * VBUS_MAX
        # MaximumPower = 3.2 * 32V
        # MaximumPower = 102.4W

        # Set Calibration register to 'Cal' calculated above
        self.write(_REG_CALIBRATION, self._cal_value)

        # Set Config register to take into account the settings above
        self.bus_voltage_range = BusVoltageRange.RANGE_32V
        self.gain = Gain.DIV_8_320MV
        self.bus_adc_resolution = ADCResolution.ADCRES_12BIT_32S
        self.shunt_adc_resolution = ADCResolution.ADCRES_12BIT_32S
        self.mode = Mode.SANDBVOLT_CONTINUOUS
        self.config = self.bus_voltage_range << 13 | \
                      self.gain << 11 | \
                      self.bus_adc_resolution << 7 | \
                      self.shunt_adc_resolution << 3 | \
                      self.mode
        self.write(_REG_CONFIG, self.config)

    def getShuntVoltage_mV(self):
        self.write(_REG_CALIBRATION, self._cal_value)
        value = self.read(_REG_SHUNTVOLTAGE)
        if value > 32767:
            value -= 65535
        return value * 0.01

    def getBusVoltage_V(self):
        self.write(_REG_CALIBRATION, self._cal_value)
        self.read(_REG_BUSVOLTAGE)
        return (self.read(_REG_BUSVOLTAGE) >> 3) * 0.004

    def getCurrent_mA(self):
        value = self.read(_REG_CURRENT)
        if value > 32767:
            value -= 65535
        return value * self._current_lsb

    def getPower_W(self):
        self.write(_REG_CALIBRATION, self._cal_value)
        value = self.read(_REG_POWER)
        if value > 32767:
            value -= 65535
        return value * self._power_lsb


if __name__ == '__main__':

    # Create an INA219 instance.
    ina219 = INA219(addr=0x42)
    while True:
        bus_voltage = ina219.getBusVoltage_V()  # voltage on V- (load side)
        shunt_voltage = ina219.getShuntVoltage_mV() / 1000  # voltage between V+ and V- across the shunt
        current = ina219.getCurrent_mA()  # current in mA
        power = ina219.getPower_W()  # power in W
        p = (bus_voltage - 6) / 2.4 * 100
        if (p > 100): p = 100
        if (p < 0): p = 0

        # INA219 measure bus voltage on the load side. So PSU voltage = bus_voltage + shunt_voltage
        # print("PSU Voltage:   {:6.3f} V".format(bus_voltage + shunt_voltage))
        # print("Shunt Voltage: {:9.6f} V".format(shunt_voltage))
        print("Load Voltage:  {:6.3f} V".format(bus_voltage))
        print("Current:       {:9.6f} A".format(current / 1000))
        print("Power:         {:6.3f} W".format(power))
        print("Percent:       {:3.1f}%".format(p))
        print("")

        time.sleep(2)

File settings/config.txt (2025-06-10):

# For more options and information see
# http://rptl.io/configtxt
# Some settings may impact device functionality. See link above for details

# Uncomment some or all of these to enable the optional hardware interfaces
dtparam=i2c_arm=on
#dtparam=i2s=on
dtparam=spi=off

# Enable audio (loads snd_bcm2835)
dtparam=audio=on

# Additional overlays and parameters are documented
# /boot/firmware/overlays/README

# Automatically load overlays for detected cameras
camera_auto_detect=1

# Automatically load overlays for detected DSI displays
display_auto_detect=1

# Automatically load initramfs files, if found
auto_initramfs=1

# Enable DRM VC4 V3D driver
dtoverlay=vc4-kms-v3d
max_framebuffers=2

# Don't have the firmware create an initial video= setting in cmdline.txt.
# Use the kernel's default instead.
disable_fw_kms_setup=1

# Run in 64-bit mode
arm_64bit=1

# Disable compensation for displays with overscan
disable_overscan=1

# Run as fast as firmware / board allows
arm_boost=1

[cm4]
# Enable host mode on the 2711 built-in XHCI USB controller.
# This line should be removed if the legacy DWC2 controller is required
# (e.g. for USB device mode) or if USB support is not required.
otg_mode=1

[cm5]
dtoverlay=dwc2,dr_mode=host

[all]
dtoverlay=vc4-kms-v3d
dtoverlay=vc4-kms-dsi-waveshare-panel,8_0_inch

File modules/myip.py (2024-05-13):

import random
import re
import requests
import dns.resolver

# DNS and HTTP lists
dns_queries = [
    ("myip.opendns.com", "resolver1.opendns.com"),
    ("myip.opendns.com", "resolver2.opendns.com"),
    ("myip.opendns.com", "resolver3.opendns.com"),
    ("myip.opendns.com", "resolver4.opendns.com"),
    ("whoami.akamai.net", "ns1-1.akamaitech.net")
]

httplist = [
    "http://alma.ch/myip.cgi",
    "http://api.infoip.io/ip",
    "http://api.ipify.org",
    "http://bot.whatismyipaddress.com",
    "http://canhazip.com",
    "http://checkip.amazonaws.com",
    "http://eth0.me",
    "http://icanhazip.com",
    "http://ident.me",
    "http://ipecho.net/plain",
    "http://ipinfo.io/ip",
    "http://ipof.in/txt",
    "http://ip.tyk.nu",
    "http://l2.io/ip",
    "http://smart-ip.net/myip",
    "http://wgetip.com",
    "http://whatismyip.akamai.com"
]

# Function to validate IP
def valid_ip(ip):
    return re.match(r'^\d{1,3}(\.\d{1,3}){3}$', ip) is not None

# Function to shuffle lists
def shuffle_list(lst):
    random.shuffle(lst)
    return lst

# Function to get IP using DNS
def get_ip_dns():
    for query, server in shuffle_list(dns_queries):
        try:
            resolver = dns.resolver.Resolver()
            resolver.nameservers = [dns.resolver.resolve(server, 'A')[0].address]
            answers = resolver.resolve(query, 'A')
            for rdata in answers:
                ip = rdata.address
                if valid_ip(ip):
                    return ip
        except (dns.exception.DNSException, IndexError):
            continue
    return None

# Function to get IP using HTTP
def get_ip_http():
    for url in shuffle_list(httplist):
        try:
            response = requests.get(url, timeout=2)
            ip = response.text.strip()
            if valid_ip(ip):
                return ip
        except requests.RequestException:
            continue
    return None

# Main function to get IP
def get_external_ip():
    ip = get_ip_dns()
    if ip is None:
        ip = get_ip_http()
        if ip is None:
            ip = "n/a"
    return ip

if __name__ == '__main__':
    print(get_external_ip())

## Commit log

2024-05-13 T-Pot Mobile v1.0
    [T-Pot Case v3.3mf, T-Pot Case v3.stl, config.txt]
2025-06-10 Prep for release of T-Pot Mobile v2.0
    [T-Pot Case 8inch Bottom.3mf, T-Pot Case 8inch Top.3mf, config.txt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]
2025-09-02 More spcific assembly info
2025-09-19 Update - Cache external IP - Wifi signal indicator with bars was confusing, now using a more typical Wifi signal indicator - Check if battery is charing before shutting down the system
